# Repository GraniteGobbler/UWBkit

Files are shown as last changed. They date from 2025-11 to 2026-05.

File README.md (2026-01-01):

# UWBkit

This is a repository containing firmware from two other repositories and is released under their license:
- [DWM3001C-starter-firmware](https://github.com/Uberi/DWM3001C-starter-firmware), by Uberi (as of [02c341b](https://github.com/Uberi/DWM3001C-starter-firmware/commit/02c341b4f58dd8410239b5278b40aece675a3650))
- [SSD1306-LCD-on-NRF52](https://github.com/jimmywong2003/SSD1306-LCD-on-NRF52), by jimmywong2003 (as of [4ca746a](https://github.com/jimmywong2003/SSD1306-LCD-on-NRF52/commit/4ca746a075d3628c971d63ee42bb9b67d5787345))

All other files are released under the [Creative Commons CC0 license](https://creativecommons.org/public-domain/cc0/).

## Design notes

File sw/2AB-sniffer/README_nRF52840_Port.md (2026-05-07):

# DWM3001C Starter Firmware – nRF52840 Port

This directory contains all files needed to build the
[DWM3001C starter firmware](https://github.com/Uberi/DWM3001C-starter-firmware)
for an **nRF52840**-based board inside **SEGGER Embedded Studio (SES) v7+**.

---

## Files in this port

| File | Purpose |
|---|---|
| `dw3000_api_nrf52840.emProject` | SES solution/project file (drop-in replacement for the original `dw3000_api.emProject`) |
| `flash_placement_nrf52840.xml` | Linker section-placement descriptor (1 MB Flash, 256 KB RAM) |
| `Setup/SEGGER_Flash_nrf52840.icf` | IAR/SEGGER linker script for nRF52840 |
| `Src/platform/custom_board_nrf52840.h` | GPIO / SPI pin definitions for the DW3000 ↔ nRF52840 wiring |
| `Src/platform/sdk_config_nrf52840.h` | nRF5 SDK `sdk_config` overrides (SPIM3, GPIOTE, logging, …) |

---

## Key differences from the nRF52833 (DWM3001C) project

| Setting | nRF52833 (original) | nRF52840 (this port) |
|---|---|---|
| `arm_target_device_name` | `nRF52833_xxAA` | `nRF52840_xxAA` |
| Preprocessor define | `NRF52833_XXAA` | `NRF52840_XXAA` |
| System init | `system_nrf52833.c` | `system_nrf52840.c` |
| Startup files | `ses_startup_nrf52833.s` | `ses_startup_nrf52840.s` |
| SVD file | `nrf52833.svd` | `nrf52840.svd` |
| Flash size | 512 KB (0x80000) | 1 MB (0x100000) |
| RAM size | 128 KB (0x20000) | **256 KB (0x40000)** |
| Linker script | `Setup/SEGGER_Flash.icf` | `Setup/SEGGER_Flash_nrf52840.icf` |
| Flash placement XML | `flash_placement.xml` | `flash_placement_nrf52840.xml` |

The SPI peripheral (SPIM3, 32 MHz capable) and the nrfx/legacy driver layer are
identical between the two chips, so **no changes to `deca_spi.c`, `port.c`, or any
example source files are required.**

---

## Prerequisites

1. **SEGGER Embedded Studio** v7.x (free for Nordic targets).
2. **nRF5 SDK 17.1.0** (`nRF5_SDK_17.1.0_ddde560`) extracted to
   `/usr/local/nRF5_SDK_17.1.0_ddde560` **or** update the `NordicSDKDir` macro
   inside `dw3000_api_nrf52840.emProject` to match your installation path.
3. A **J-Link** (on-board on nRF52840-DK) for flashing and RTT logging.

---

## Setup steps

### 1 – Copy port files into the repository

Copy all files from this port directory into the root of the cloned
`DWM3001C-starter-firmware` repository, preserving the directory structure:

```
DWM3001C-starter-firmware/
├── dw3000_api_nrf52840.emProject      ← new
├── flash_placement_nrf52840.xml       ← new
├── Setup/
│   ├── SEGGER_Flash.icf               (original, untouched)
│   └── SEGGER_Flash_nrf52840.icf      ← new
└── Src/
    └── platform/
        ├── custom_board_nrf52840.h    ← new
        ├── sdk_config_nrf52840.h      ← new
        └── ... (original files unchanged)
```

### 2 – Tell the SDK about the custom board

The project uses `BOARD_CUSTOM`.  The nRF5 SDK expects a file called `custom_board.h`
on the include path.  Create a thin wrapper in `Src/platform/custom_board.h`:

```c
/* Src/platform/custom_board.h */
#pragma once
#include "custom_board_nrf52840.h"
```

> If you already have a `custom_board.h` for a different board, rename it and
> adjust the include accordingly.

### 3 – Set the NordicSDKDir macro

In SES: **Tools → Options → Building → Global macros**, set:

```
NordicSDKDir=<absolute path to nRF5_SDK_17.1.0_ddde560>
```

Or edit the `macros` attribute directly in `dw3000_api_nrf52840.emProject`.

### 4 – Open and build

1. Open `dw3000_api_nrf52840.emProject` in SES.
2. Select the **Debug** configuration.
3. Choose the example to run by editing `Src/main.c` (same as the original project).
4. Build (**F7**) and flash (**F5**).

---

## Pin wiring (nRF52840-DK default)

| DW3000 signal | nRF52840 GPIO | nRF52840-DK header |
|---|---|---|
| SPI CLK | P0.03 | D13 |
| SPI MOSI | P0.04 | D11 |
| SPI MISO | P0.28 | D12 |
| SPI CS | P0.29 | D10 |
| IRQ | P0.30 | D9 |
| RST | P0.31 | D8 |
| WAKEUP | P0.02 | D7 |

Adjust `custom_board_nrf52840.h` if your hardware uses different pins.

---

## Troubleshooting

| Symptom | Likely cause | Fix |
|---|---|-----|
| Build error: `nrf52840.h not found` | Wrong SDK path | Update `NordicSDKDir` |
| Build error: `ses_startup_nrf52840.s not found` | SDK < 15.3 | Use SDK 17.1.0 |
| Device not recognised by J-Link | Wrong target in project | Confirm `arm_target_device_name="nRF52840_xxAA"` |
| SPI transfer returns garbage | Wrong pin numbers | Re-check `custom_board_nrf52840.h` |
| RTT output missing | `NRF_LOG_BACKEND_RTT_ENABLED` not set | Ensure `sdk_config_nrf52840.h` is included |

---

## License

This port is provided under the same terms as the upstream project (Apache 2.0).
The nRF5 SDK files referenced by the project file are subject to Nordic's
[5-clause Nordic license](https://developer.nordicsemi.com/nRF5_SDK/nRF5_SDK_v17.x.x/sdk_license.zip).

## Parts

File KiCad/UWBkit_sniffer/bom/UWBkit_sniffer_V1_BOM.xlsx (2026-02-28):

Reference | Qty | Qty Owned | Qty Need | Value | Footprint | Mouser link
ANT1 | 1 | 0 | 1 | Taoglas_UWC.20 | UWB_Antennas:Taoglas_UWC.20 | https://cz.mouser.com/ProductDetail/Taoglas/UWC.20?qs=MLItCLRbWswWjiq9Fti3WQ%3D%3D
C1,C3,C6,C9,C11,C12 | 6 | 6 | 0 | 100n | Capacitor_SMD:C_0603_1608Metric
C2,C4 | 2 | 8 | -6 | 10u | Capacitor_Tantalum_SMD:CP_EIA-3216-18_Kemet-A
C5 | 1 | 0 | 1 | 0R | Capacitor_SMD:C_0603_1608Metric | https://cz.mouser.com/ProductDetail/Panasonic/ERJ-H3G0R00V?qs=eP2BKZSCXI4lQ49QwEWHxw%3D%3D
C7,C8 | 2 | 6 | -4 | 10u | Capacitor_SMD:C_0603_1608Metric
C10 | 1 | 0 | 1 | 1u | Capacitor_Tantalum_SMD:CP_EIA-3216-18_Kemet-A | https://cz.mouser.com/ProductDetail/KEMET/T491A105K020ATAUTO?qs=WOKUqv%2F%2FT%2Fa0doDrQU37QA%3D%3D
D1,D2,D4,D5 | 4 | 4 | 0 | R | LED_SMD:LED_0603_1608Metric
D3,D6 | 2 | 2 | 0 | G | LED_SMD:LED_0603_1608Metric
H1,H2,H3,H4 | 4 | 4 | 0 | MountingHole_Pad | MountingHole:MountingHole_3.2mm_M3_Pad_Via
J1 | 1 | 1 | 0 | Conn_I2C1 | Connector_PinSocket_2.54mm:PinSocket_1x04_P2.54mm_Vertical
J2 | 1 | 1 | 0 | Conn_I2C2 | Connector_PinSocket_2.54mm:PinSocket_1x04_P2.54mm_Vertical
J3 | 1 | 1 | 0 | Conn_01x03 | Connector_PinSocket_2.54mm:PinSocket_1x03_P2.54mm_Vertical
J4 | 1 | 1 | 0 | Conn_SPIS | Connector_PinSocket_2.54mm:PinSocket_1x07_P2.54mm_Vertical
J5 | 1 | 1 | 0 | Conn_SPIM | Connector_PinSocket_2.54mm:PinSocket_1x07_P2.54mm_Vertical
J6 | 1 | 0 | 1 | Conn_SWD | Connector_PinHeader_1.27mm:PinHeader_2x05_P1.27mm_Vertical_SMD | https://cz.mouser.com/ProductDetail/Samtec/FTSH-105-01-F-DV-K-A?qs=rU5fayqh%252BE2B26KBQKnaPw%3D%3D
J7 | 1 | 1 | 0 | Conn_GPIO | Connector_PinSocket_2.54mm:PinSocket_2x04_P2.54mm_Vertical
J8 | 1 | 0 | 1 | Conn_Coaxial | Connector_Coaxial:SMA_Molex_73251-1153_EdgeMount_Horizontal | https://cz.mouser.com/ProductDetail/Molex/73251-1153?qs=vxeUf0TWHS0zlj4xWb5GCw%3D%3D
J9 | 1 | 1 | 0 | Conn_01x02 | Connector_PinHeader_2.54mm:PinHeader_1x02_P2.54mm_Vertical
J10,J11 | 2 | 1 | 1 | USB_C_Receptacle_USB2.0_14P | Connector_USB:USB_C_Receptacle_GCT_USB4105-xx-A_16P_TopMnt_Horizontal | https://cz.mouser.com/ProductDetail/GCT/USB4105-GF-A?qs=KUoIvG%2F9IlY%2FMLlBMpStpA%3D%3D
L1,L2 (DNP) | 2 | 2 | 0 | L | Inductor_SMD:L_0603_1608Metric
L3 | 1 | 8 | -7 | 2.2u | Inductor_SMD:L_0805_2012Metric
R1,R2,R9 (DNP) | 3 | 3 | 0 | 0R | Resistor_SMD:R_0603_1608Metric
R3,R11 | 2 | 15 | -13 | 100k | Resistor_SMD:R_0603_1608Metric
R4,R5,R10,R15 | 4 | 0 | 4 | 3k3 | Resistor_SMD:R_0603_1608Metric | https://cz.mouser.com/ProductDetail/YAGEO/RC0603FR-073K3L?qs=gt6vzsuosg2EoNiKbtAsfQ%3D%3D
R6,R16 | 2 | 0 | 2 | 2k1 | Resistor_SMD:R_0603_1608Metric | https://cz.mouser.com/ProductDetail/YAGEO/RC0603FR-072K1L?qs=IuGqVx9wL0IQ8qvrNmtVmg%3D%3D
R7,R8,R13 | 3 | 3 | 0 | 0R | Resistor_SMD:R_0603_1608Metric
R12 | 1 | 0 | 1 | 24k | Resistor_SMD:R_0603_1608Metric | https://cz.mouser.com/ProductDetail/YAGEO/RC0603FR-1024KL?qs=EiqXWrxQq63LblM5DPLYDA%3D%3D
R14 | 1 | 0 | 1 | 47k | Resistor_SMD:R_0603_1608Metric | https://cz.mouser.com/ProductDetail/YAGEO/AC0603FR-1347KL?qs=1mbolxNpo8d0iSUsjFUAXQ%3D%3D
R17,R18,R20,R21 | 4 | 6 | -2 | 5k1 | Resistor_SMD:R_0603_1608Metric
R19,R22 | 2 | 8 | -6 | 10k | Resistor_SMD:R_0603_1608Metric
SW1 | 1 | 1 | 0 | SW_Push | Button_Switch_THT:SW_TH_Tactile_Omron_B3F-106x
U1 | 1 | 0 | 1 | LBUA5QJ2AB | LBUA5QJ2AB:LBUA5QJ2AB | https://cz.mouser.com/ProductDetail/Murata/LBUA5QJ2AB-828?qs=By6Nw2ByBD3tGvEImOEzYQ%3D%3D
U2 | 1 | 0 | 1 | XC9285B33CMR-G | Package_TO_SOT_SMD:SOT-23-5 | https://cz.mouser.com/ProductDetail/Torex-Semiconductor/XC9285B33CMR-G?qs=dbcCsuKDzFUopNkosMcCjA%3D%3D
U3 | 1 | 0 | 1 | CP2104 | Package_DFN_QFN:QFN-24-1EP_4x4mm_P0.5mm_EP2.6x2.6mm | https://cz.mouser.com/ProductDetail/Silicon-Labs/CP2104-F03-GMR?qs=1CB38rTTsYrRJKVkczeRzA%3D%3D
U4,U5 | 2 | 1 | 1 | IP4234CZ6 | Package_TO_SOT_SMD:SC-74-6_1.55x2.9mm_P0.95mm | https://cz.mouser.com/ProductDetail/STMicroelectronics/USBLC6-4SC6Y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
0R |  |  | 7

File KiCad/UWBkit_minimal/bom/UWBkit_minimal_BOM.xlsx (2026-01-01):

Reference | Qty | Value | Footprint |  | Mouser link
BT1 | 1 | CR2032 | Battery:BatteryHolder_Keystone_1058_1x2032 | https://cz.mouser.com/ProductDetail/Keystone-Electronics/1058?qs=1Og3oR3ILyCdlFdchHwycQ%3D%3D | https://cz.mouser.com/ProductDetail/Keystone-Electronics/1058?qs=1Og3oR3ILyCdlFdchHwycQ%3D%3D
C1,C3,C4 | 3 | 100n | Capacitor_SMD:C_0603_1608Metric | https://cz.mouser.com/ProductDetail/YAGEO/CC0603JRX7R9BB104?qs=57cj7OiSijmjSM%252BQadQODQ%3D%3D | https://cz.mouser.com/ProductDetail/YAGEO/CC0603JRX7R9BB104?qs=57cj7OiSijmjSM%252BQadQODQ%3D%3D
C2 | 1 | 10u | Capacitor_Tantalum_SMD:CP_EIA-3216-18_Kemet-A | https://cz.mouser.com/ProductDetail/KEMET/T491A106K010AT7280?qs=sGAEpiMZZMtZ1n0r9vR22Xj1zlb9nzH05nChlkMPHIM%3D | https://cz.mouser.com/ProductDetail/KEMET/T491A106K010AT7280?qs=sGAEpiMZZMtZ1n0r9vR22Xj1zlb9nzH05nChlkMPHIM%3D
C5,C6 | 2 | 10u | Capacitor_SMD:C_0603_1608Metric | https://cz.mouser.com/ProductDetail/Murata-Electronics/GRM188Z71A106KA73D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 | https://cz.mouser.com/ProductDetail/Murata-Electronics/GRM188Z71A106KA73D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
D1 | 1 | G | LED_SMD:LED_0603_1608Metric | https://cz.mouser.com/ProductDetail/Wurth-Elektronik/150060GS83000?qs=3GbUB62Nf7fgC6%2FTmce6tQ%3D%3D | https://cz.mouser.com/ProductDetail/Wurth-Elektronik/150060GS83000?qs=3GbUB62Nf7fgC6%2FTmce6tQ%3D%3D
D2 | 1 | B | LED_SMD:LED_0603_1608Metric | https://cz.mouser.com/ProductDetail/Wurth-Elektronik/150060BS83000?qs=3GbUB62Nf7dydBCOIPGfOA%3D%3D | https://cz.mouser.com/ProductDetail/Wurth-Elektronik/150060BS83000?qs=3GbUB62Nf7dydBCOIPGfOA%3D%3D
D3,D5,D6 | 3 | R | LED_SMD:LED_0603_1608Metric | https://cz.mouser.com/ProductDetail/Wurth-Elektronik/150060RS83000?qs=3GbUB62Nf7cMzk8OPkCLhg%3D%3D | https://cz.mouser.com/ProductDetail/Wurth-Elektronik/150060RS83000?qs=3GbUB62Nf7cMzk8OPkCLhg%3D%3D
D4 | 1 | LSG T676-P7R-1-0+N7P9-24 | LED_Dual:LED_Dual_OSRAM-PLCC4_3.2x2.8mm | https://cz.mouser.com/ProductDetail/ams-OSRAM/LSG-T676-P7R-1-0%2bN7P9-24?qs=74fRo9GAWsxURNkIJamEtQ%3D%3D | https://cz.mouser.com/ProductDetail/ams-OSRAM/LSG-T676-P7R-1-0%2bN7P9-24?qs=74fRo9GAWsxURNkIJamEtQ%3D%3D
D7 | 1 | PESD5V2S2UT | Package_TO_SOT_SMD:SOT-23 | https://cz.mouser.com/ProductDetail/Nexperia/PESD5V2S2UT-QR?qs=vvQtp7zwQdMj81rXubab%2Fw%3D%3D | https://cz.mouser.com/ProductDetail/Nexperia/PESD5V2S2UT-QR?qs=vvQtp7zwQdMj81rXubab%2Fw%3D%3D
J1 | 1 | Conn_UART | Connector_PinSocket_2.54mm:PinSocket_1x04_P2.54mm_Vertical | https://cz.mouser.com/ProductDetail/Samtec/SSQ-104-01-G-S?qs=rU5fayqh%252BE3vCiJshtNkaw%3D%3D | https://cz.mouser.com/ProductDetail/Samtec/SSQ-104-01-G-S?qs=rU5fayqh%252BE3vCiJshtNkaw%3D%3D
J2 | 1 | Conn_SWD | Connector_PinHeader_1.27mm:PinHeader_2x05_P1.27mm_Vertical_SMD | https://cz.mouser.com/ProductDetail/Samtec/SHF-105-01-L-D-SM?qs=92ilVni64gzDB%252BvALG5zyg%3D%3D | https://cz.mouser.com/ProductDetail/Samtec/SHF-105-01-L-D-SM?qs=92ilVni64gzDB%252BvALG5zyg%3D%3D
J3 | 1 | USB_C_Receptacle_USB2.0_14P | Connector_USB:USB_C_Receptacle_GCT_USB4105-xx-A_16P_TopMnt_Horizontal | https://cz.mouser.com/ProductDetail/GCT/USB4105-GF-A?qs=KUoIvG%2F9IlY%2FMLlBMpStpA%3D%3D | https://cz.mouser.com/ProductDetail/GCT/USB4105-GF-A?qs=KUoIvG%2F9IlY%2FMLlBMpStpA%3D%3D
J4 | 1 | Conn_BATT | Connector_PinSocket_2.54mm:PinSocket_1x02_P2.54mm_Vertical | https://cz.mouser.com/ProductDetail/Amphenol-FCI/76308-102LF?qs=5xI8GKdkXlk3acvGut782g%3D%3D | https://cz.mouser.com/ProductDetail/Amphenol-FCI/76308-102LF?qs=5xI8GKdkXlk3acvGut782g%3D%3D
J5 | 1 | Jumper_Cell_NO | Connector_PinHeader_2.54mm:PinHeader_1x02_P2.54mm_Vertical | https://cz.mouser.com/ProductDetail/Amphenol-FCI/10129378-910002BLF?qs=0lQeLiL1qyYh8zFHsKDebQ%3D%3D | https://cz.mouser.com/ProductDetail/Amphenol-FCI/10129378-910002BLF?qs=0lQeLiL1qyYh8zFHsKDebQ%3D%3D
L1 | 1 | 2.2u | Inductor_SMD:L_0805_2012Metric | https://cz.mouser.com/ProductDetail/TDK/MLZ2012M2R2HT000?qs=%2FPzWLGNeQ%252BjH4aKH16QzxA%3D%3D | https://cz.mouser.com/ProductDetail/TDK/MLZ2012M2R2HT000?qs=%2FPzWLGNeQ%252BjH4aKH16QzxA%3D%3D
Q1,Q2 | 2 | BSS138 | Package_TO_SOT_SMD:SOT-23 | https://cz.mouser.com/ProductDetail/onsemi-Fairchild/BSS138?qs=HK%252BeIG1iaahCeqBvjB4arg%3D%3D | https://cz.mouser.com/ProductDetail/onsemi-Fairchild/BSS138?qs=HK%252BeIG1iaahCeqBvjB4arg%3D%3D
Q3 | 1 | BSS84 | Package_TO_SOT_SMD:SOT-23-3 | https://cz.mouser.com/ProductDetail/onsemi-Fairchild/BSS84?qs=FOlmdCx%252BAA0e83h5MpSc0g%3D%3D | https://cz.mouser.com/ProductDetail/onsemi-Fairchild/BSS84?qs=FOlmdCx%252BAA0e83h5MpSc0g%3D%3D
R1 | 1 | 200R | Resistor_SMD:R_0603_1608Metric | https://cz.mouser.com/ProductDetail/YAGEO/RT0603DRD07200RL | https://cz.mouser.com/ProductDetail/YAGEO/RT0603DRD07200RL
R2 | 1 | 30R | Resistor_SMD:R_0603_1608Metric | https://cz.mouser.com/ProductDetail/YAGEO/RT0603DRE0730RL?qs=sGAEpiMZZMvdGkrng054t98Xz4DA4UW4YZV2RawqRNs%3D | https://cz.mouser.com/ProductDetail/YAGEO/RT0603DRE0730RL?qs=sGAEpiMZZMvdGkrng054t98Xz4DA4UW4YZV2RawqRNs%3D
R3 | 1 | 150R | Resistor_SMD:R_0603_1608Metric | https://cz.mouser.com/ProductDetail/YAGEO/AC0603FR-10150RL | https://cz.mouser.com/ProductDetail/YAGEO/AC0603FR-10150RL
R4 | 1 | 330R | Resistor_SMD:R_0603_1608Metric | https://cz.mouser.com/ProductDetail/YAGEO/RE0603FRE07330RL | https://cz.mouser.com/ProductDetail/YAGEO/RE0603FRE07330RL
R5 | 1 | 220R | Resistor_SMD:R_0603_1608Metric | https://cz.mouser.com/ProductDetail/Vishay/CRCW0603220RFKEC | https://cz.mouser.com/ProductDetail/Vishay/CRCW0603220RFKEC
R6,R9,R15 | 3 | 300R | Resistor_SMD:R_0603_1608Metric | https://cz.mouser.com/ProductDetail/Panasonic/ERA-3AEB301V | https://cz.mouser.com/ProductDetail/Panasonic/ERA-3AEB301V
R7,R8 | 2 | 5k1 | Resistor_SMD:R_0603_1608Metric | https://cz.mouser.com/ProductDetail/Vishay/CRCW06035K10FKEBC | https://cz.mouser.com/ProductDetail/Vishay/CRCW06035K10FKEBC
R10,R11 | 2 | 1k | Resistor_SMD:R_0603_1608Metric | https://cz.mouser.com/ProductDetail/Vishay-Draloric/RCA06031K00FKEA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 | https://cz.mouser.com/ProductDetail/Vishay-Draloric/RCA06031K00FKEA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
R12,R13,R16 | 3 | 100k | Resistor_SMD:R_0603_1608Metric | https://cz.mouser.com/ProductDetail/YAGEO/RT0603BRD07100KL | https://cz.mouser.com/ProductDetail/YAGEO/RT0603BRD07100KL
R14 | 1 | 10k | Resistor_SMD:R_0603_1608Metric | https://cz.mouser.com/ProductDetail/YAGEO/RC0603FR-7W10KL | https://cz.mouser.com/ProductDetail/YAGEO/RC0603FR-7W10KL
SW1 | 1 | SW_Push | Button_Switch_THT:SW_TH_Tactile_Omron_B3F-106x | https://cz.mouser.com/ProductDetail/Omron-Electronics/B3F-1060 | https://cz.mouser.com/ProductDetail/Omron-Electronics/B3F-1060
U2 | 1 | IP4234CZ6 | Package_TO_SOT_SMD:SC-74-6_1.55x2.9mm_P0.95mm | https://cz.mouser.com/ProductDetail/Nexperia/IP4234CZ6125?qs=sSXnapcmqSskfgXn%2F9aKzA%3D%3D | https://cz.mouser.com/ProductDetail/Nexperia/IP4234CZ6125?qs=sSXnapcmqSskfgXn%2F9aKzA%3D%3D
U3 | 1 | MAX40203AUK+T | Package_TO_SOT_SMD:SOT-23-5 | https://cz.mouser.com/ProductDetail/Analog-Devices-Maxim-Integrated/MAX40203AUK%2bT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 | https://cz.mouser.com/ProductDetail/Analog-Devices-Maxim-Integrated/MAX40203AUK%2bT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
U4 | 1 | XC9285B33CMR-G | Package_TO_SOT_SMD:SOT-23-5 | https://cz.mouser.com/ProductDetail/Torex-Semiconductor/XC9285B33CMR-G?qs=dbcCsuKDzFUopNkosMcCjA%3D%3D | https://cz.mouser.com/ProductDetail/Torex-Semiconductor/XC9285B33CMR-G?qs=dbcCsuKDzFUopNkosMcCjA%3D%3D

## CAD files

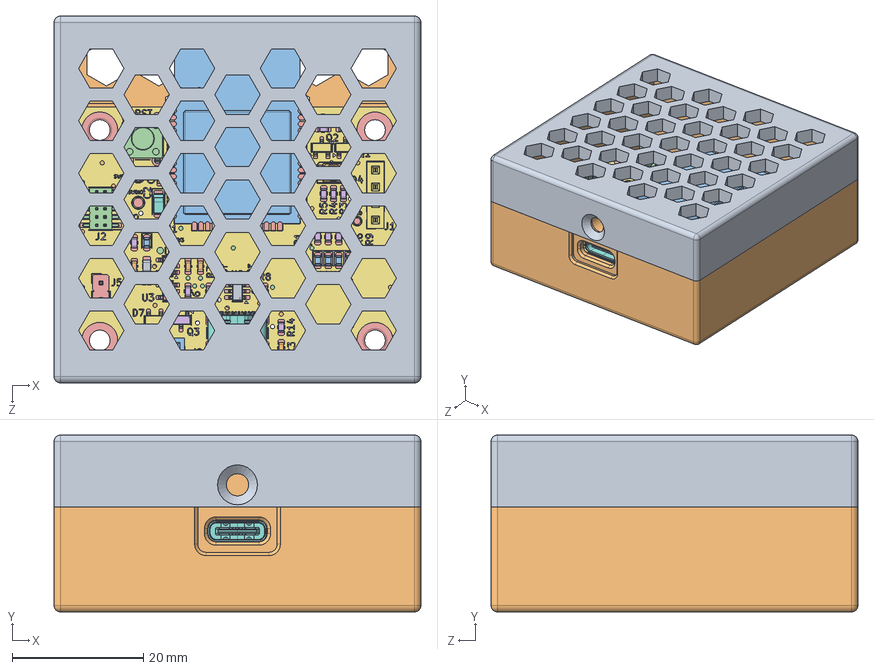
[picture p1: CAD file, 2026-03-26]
hw/UWBkit_minimal/Assem1.SLDASM
56.0 x 27.0 x 56.0 mm
case
lid
LED_0603_1608Metric.step x 5
SW_PUSH_6mm_H7.3mm.step
SOT-23-5.step x 2
R_0603_1608Metric.step x 16
SOT-23.step x 3
CP_EIA-3216-18_Kemet-A.step
L_0805_2012Metric.step
C_0603_1608Metric.step x 5
PinSocket_1x02_P2.54mm_Vertical.step
PinHeader_2x05_P1.27mm_Vertical_SMD.step
PinHeader_1x02_P2.54mm_Vertical.step
SOT-23-3.step
PinSocket_1x04_P2.54mm_Vertical.step
USB_C_Receptacle_GCT_USB4105-xx-A_16P_TopMnt_Horizontal.step
SC-74-6_1.55x2.9mm_P0.95mm.step
LED_RGB_Wuerth-PLCC4_3.2x2.8mm_150141M173100.step
DWM3001C.step
BatteryHolder_Keystone_1058_1x2032.step
UWBkit_minimal_pad.step
UWBkit_minimal_silkscreen.step
UWBkit_minimal_soldermask.step

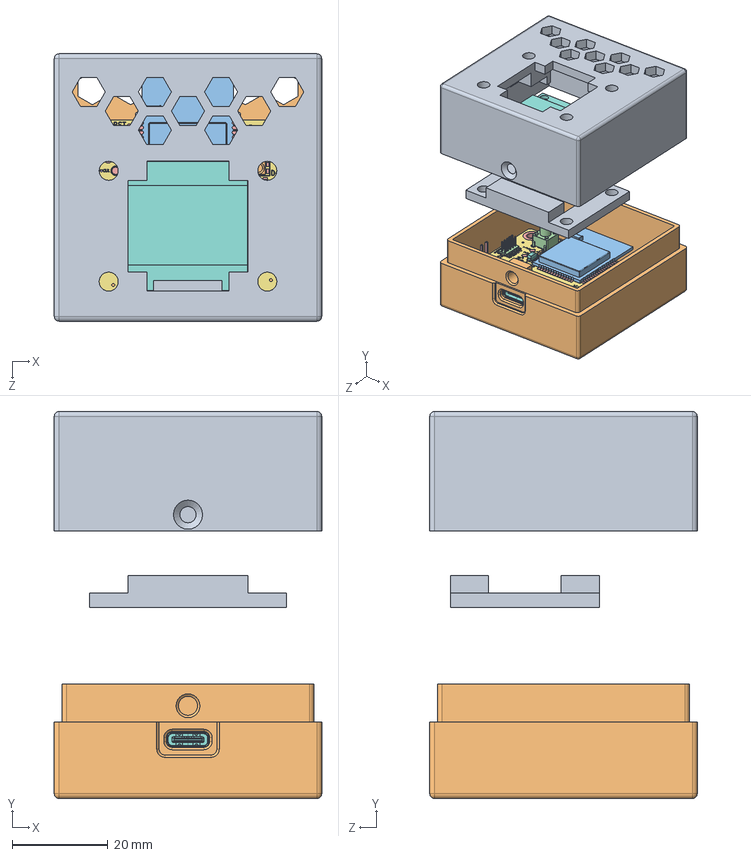
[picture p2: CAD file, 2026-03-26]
hw/UWBkit_minimal/Assem_oled.SLDASM
56.0 x 81.0 x 56.0 mm
case
LED_0603_1608Metric.step x 5
SW_PUSH_6mm_H7.3mm.step
SOT-23-5.step x 2
R_0603_1608Metric.step x 16
SOT-23.step x 3
CP_EIA-3216-18_Kemet-A.step
L_0805_2012Metric.step
C_0603_1608Metric.step x 5
PinSocket_1x02_P2.54mm_Vertical.step
PinHeader_2x05_P1.27mm_Vertical_SMD.step
PinHeader_1x02_P2.54mm_Vertical.step
SOT-23-3.step
PinSocket_1x04_P2.54mm_Vertical.step
USB_C_Receptacle_GCT_USB4105-xx-A_16P_TopMnt_Horizontal.step
SC-74-6_1.55x2.9mm_P0.95mm.step
LED_RGB_Wuerth-PLCC4_3.2x2.8mm_150141M173100.step
DWM3001C.step
BatteryHolder_Keystone_1058_1x2032.step
UWBkit_minimal_pad.step
UWBkit_minimal_silkscreen.step
UWBkit_minimal_soldermask.step
oled
oled_holder
lid_oled

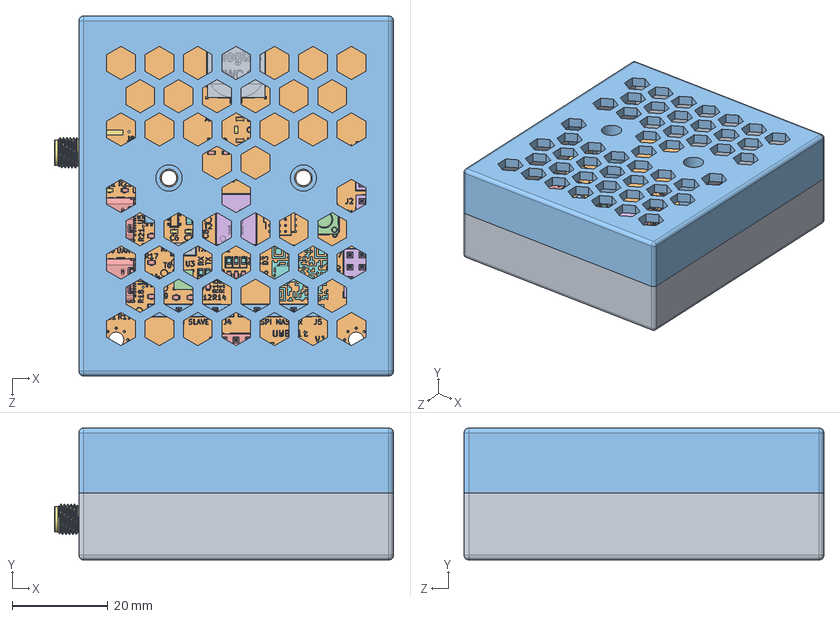
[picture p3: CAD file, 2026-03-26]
hw/UWBkit_sniffer/Assembly.SLDASM
70.6 x 27.5 x 75.0 mm
case_bottom
FTSH-105-01-F-DV-K-A_body.step
FTSH-105-01-F-DV-K_pins1.step
FTSH-105-01-F-DV-K_pins2.step
R_0603_1608Metric.step x 22
PinSocket_1x04_P2.54mm_Vertical.step x 2
C_0603_1608Metric.step x 9
LED_0603_1608Metric.step x 6
PinHeader_1x02_P2.54mm_Vertical.step
L_0603_1608Metric.step x 2
SC-74-6_1.55x2.9mm_P0.95mm.step x 2
QFN-24-1EP_4x4mm_P0.5mm_EP2.6x2.6mm.step
USB_C_Receptacle_GCT_USB4105-xx-A_16P_TopMnt_Horizontal.step x 2
PinSocket_2x04_P2.54mm_Vertical.step
SMA_Molex_73251-1153_EdgeMount_Horizontal.step
L_0805_2012Metric.step
UWC.20.step
SOT-23-5.step
PinSocket_1x07_P2.54mm_Vertical.step x 2
SW_TH_Tactile_Omron_B3F-106x.step
PinSocket_1x03_P2.54mm_Vertical.step
Type2AB.step
CP_EIA-3216-18_Kemet-A.step x 3
UWBkit_sniffer_silkscreen.step
UWBkit_sniffer_silkscreen-0.step
UWBkit_sniffer_PCB.step
case_lid

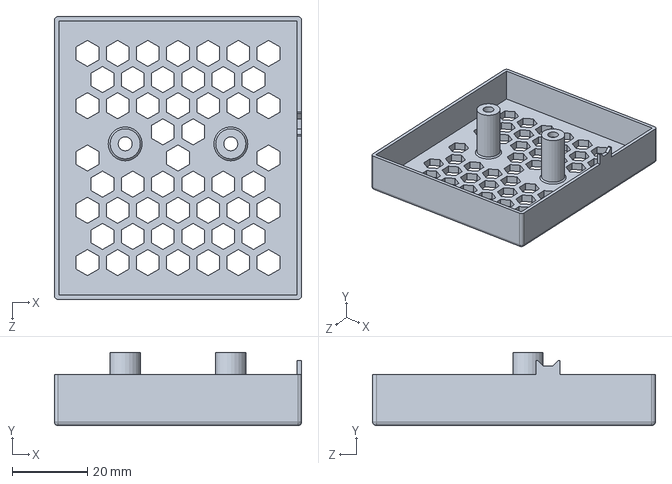
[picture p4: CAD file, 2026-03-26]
hw/UWBkit_sniffer/case_lid.SLDPRT
65.6 x 19.4 x 75.0 mm

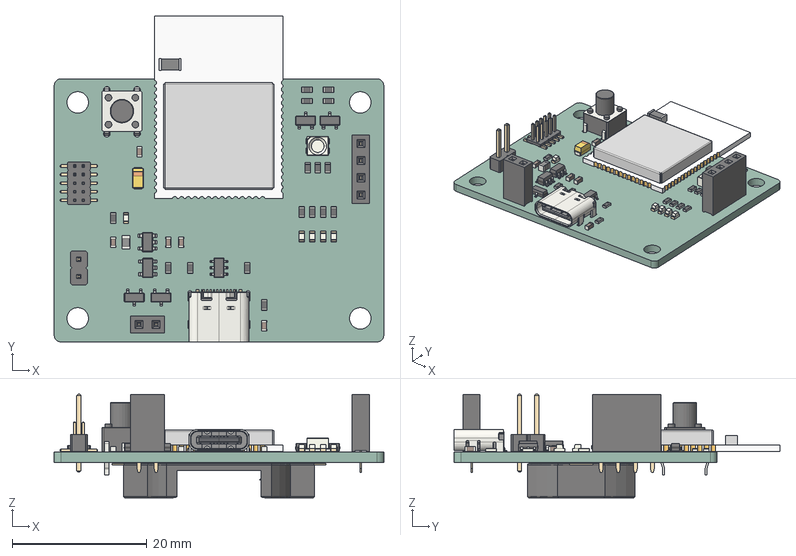
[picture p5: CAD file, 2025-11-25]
KiCad/UWBkit_minimal/UWBkit_minimal.step
49.0 x 48.5 x 15.4 mm
LED_0603_1608Metric x 5
SW_PUSH_6mm_H7.3mm
SOT-23-5 x 2
R_0603_1608Metric x 16
SOT-23 x 3
CP_EIA-3216-18_Kemet-A
L_0805_2012Metric
C_0603_1608Metric x 5
PinSocket_1x02_P2.54mm_Vertical
PinHeader_2x05_P1.27mm_Vertical_SMD
PinHeader_1x02_P2.54mm_Vertical
SOT-23-3
PinSocket_1x04_P2.54mm_Vertical
USB_C_Receptacle_GCT_USB4105-xx-A_16P_TopMnt_Horizontal
SC-74-6_1.55x2.9mm_P0.95mm
LED_RGB_Wuerth-PLCC4_3.2x2.8mm_150141M173100
DWM3001C
BatteryHolder_Keystone_1058_1x2032
UWBkit_minimal_PCB

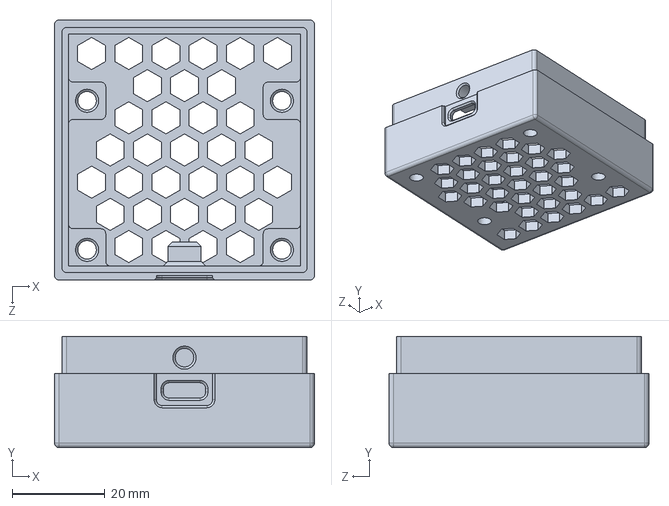
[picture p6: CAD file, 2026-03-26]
hw/UWBkit_minimal/case.SLDPRT
56.0 x 24.0 x 56.0 mm

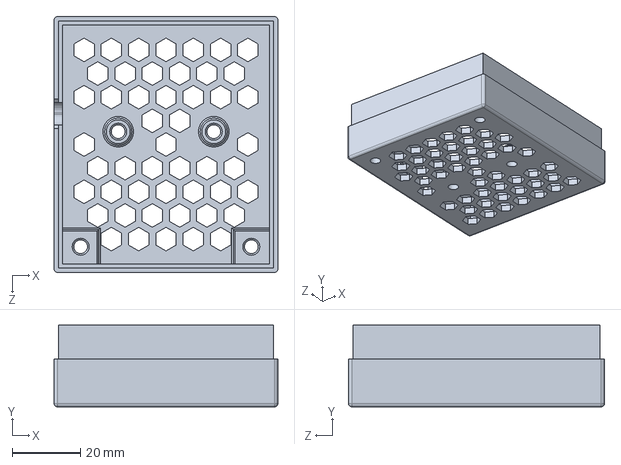
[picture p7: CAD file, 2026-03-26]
hw/UWBkit_sniffer/case_bottom.SLDPRT
65.6 x 24.0 x 75.0 mm

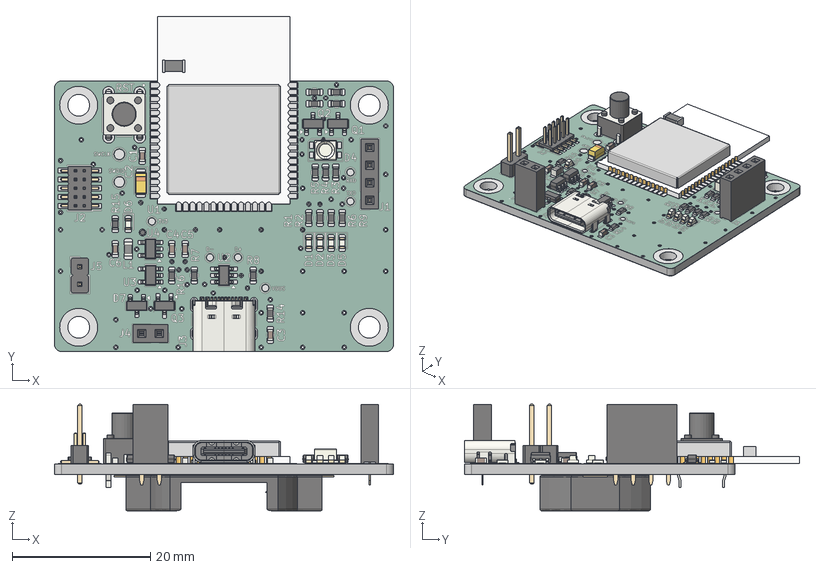
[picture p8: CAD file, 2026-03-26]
hw/UWBkit_minimal/UWBkit_minimal.step
49.0 x 48.5 x 15.4 mm
LED_0603_1608Metric x 5
SW_PUSH_6mm_H7.3mm
SOT-23-5 x 2
R_0603_1608Metric x 16
SOT-23 x 3
CP_EIA-3216-18_Kemet-A
L_0805_2012Metric
C_0603_1608Metric x 5
PinSocket_1x02_P2.54mm_Vertical
PinHeader_2x05_P1.27mm_Vertical_SMD
PinHeader_1x02_P2.54mm_Vertical
SOT-23-3
PinSocket_1x04_P2.54mm_Vertical
USB_C_Receptacle_GCT_USB4105-xx-A_16P_TopMnt_Horizontal
SC-74-6_1.55x2.9mm_P0.95mm
LED_RGB_Wuerth-PLCC4_3.2x2.8mm_150141M173100
DWM3001C
BatteryHolder_Keystone_1058_1x2032
UWBkit_minimal_pad
UWBkit_minimal_silkscreen
UWBkit_minimal_soldermask
UWBkit_minimal_PCB

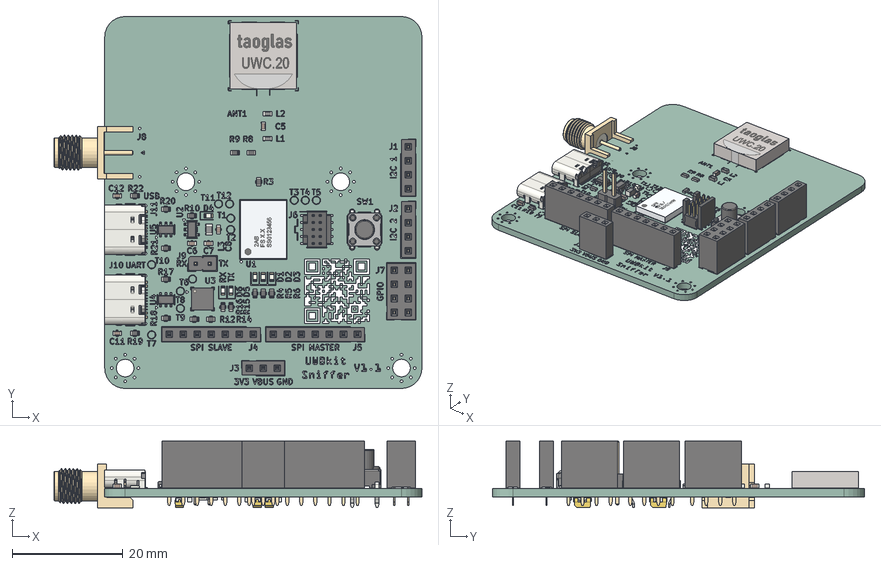
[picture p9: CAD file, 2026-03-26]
hw/UWBkit_sniffer/UWBkit_sniffer.step
66.6 x 67.3 x 12.1 mm
R_0603_1608Metric x 22
PinSocket_1x04_P2.54mm_Vertical x 2
C_0603_1608Metric x 9
FTSH-105-01-F-DV-K-A_body
FTSH-105-01-F-DV-K_pins1
FTSH-105-01-F-DV-K_pins2
LED_0603_1608Metric x 6
PinHeader_1x02_P2.54mm_Vertical
L_0603_1608Metric x 2
SC-74-6_1.55x2.9mm_P0.95mm x 2
QFN-24-1EP_4x4mm_P0.5mm_EP2.6x2.6mm
USB_C_Receptacle_GCT_USB4105-xx-A_16P_TopMnt_Horizontal x 2
PinSocket_2x04_P2.54mm_Vertical
SMA_Molex_73251-1153_EdgeMount_Horizontal
L_0805_2012Metric
UWC.20
SOT-23-5
PinSocket_1x07_P2.54mm_Vertical x 2
SW_TH_Tactile_Omron_B3F-106x
PinSocket_1x03_P2.54mm_Vertical
Type2AB
CP_EIA-3216-18_Kemet-A x 3
UWBkit_sniffer_silkscreen x 2
UWBkit_sniffer_PCB

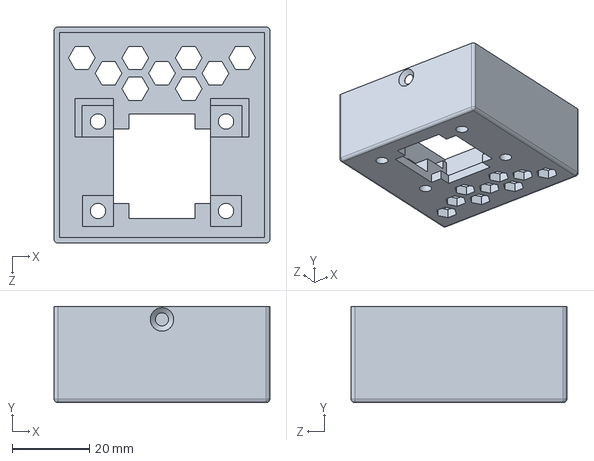
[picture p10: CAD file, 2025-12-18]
hw/UWBkit_minimal/lid_oled.SLDPRT
56.0 x 25.0 x 56.0 mm

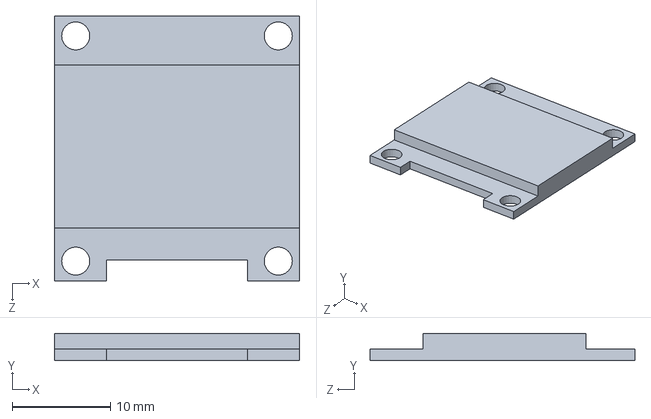
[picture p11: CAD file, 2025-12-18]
hw/UWBkit_minimal/oled.SLDPRT
25.0 x 2.80 x 27.0 mm

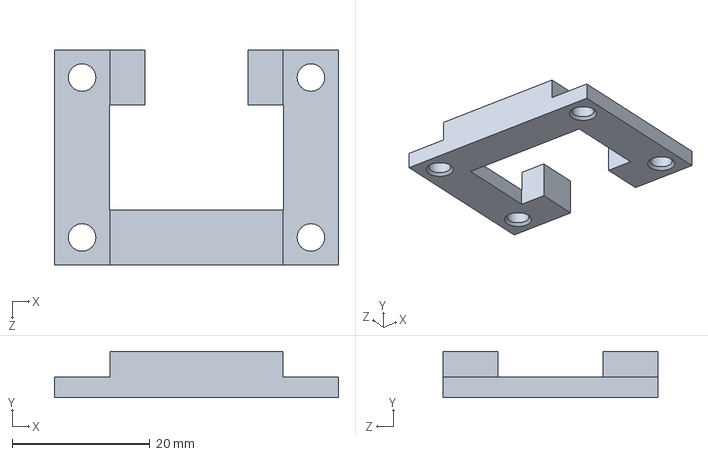
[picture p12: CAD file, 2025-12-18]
hw/UWBkit_minimal/oled_holder.SLDPRT
41.2 x 6.70 x 31.2 mm

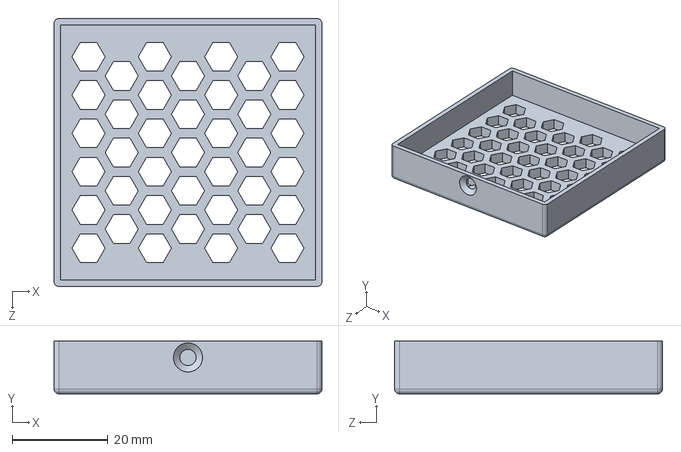
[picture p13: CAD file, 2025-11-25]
hw/UWBkit_minimal/lid.SLDPRT
56.0 x 11.0 x 56.0 mm

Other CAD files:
hw/UWBkit_sniffer/FTSH-105-01-F-DV-K.step.SLDASM
hw/UWBkit_minimal/UWBkit_minimal.SLDASM
hw/UWBkit_minimal/case.3mf
hw/UWBkit_minimal/case.STL
hw/UWBkit_minimal/lid.STL
hw/UWBkit_minimal/lid_oled.STL
hw/UWBkit_minimal/oled_holder.STL
hw/UWBkit_sniffer/case_bottom.STL
hw/UWBkit_sniffer/case_lid.STL

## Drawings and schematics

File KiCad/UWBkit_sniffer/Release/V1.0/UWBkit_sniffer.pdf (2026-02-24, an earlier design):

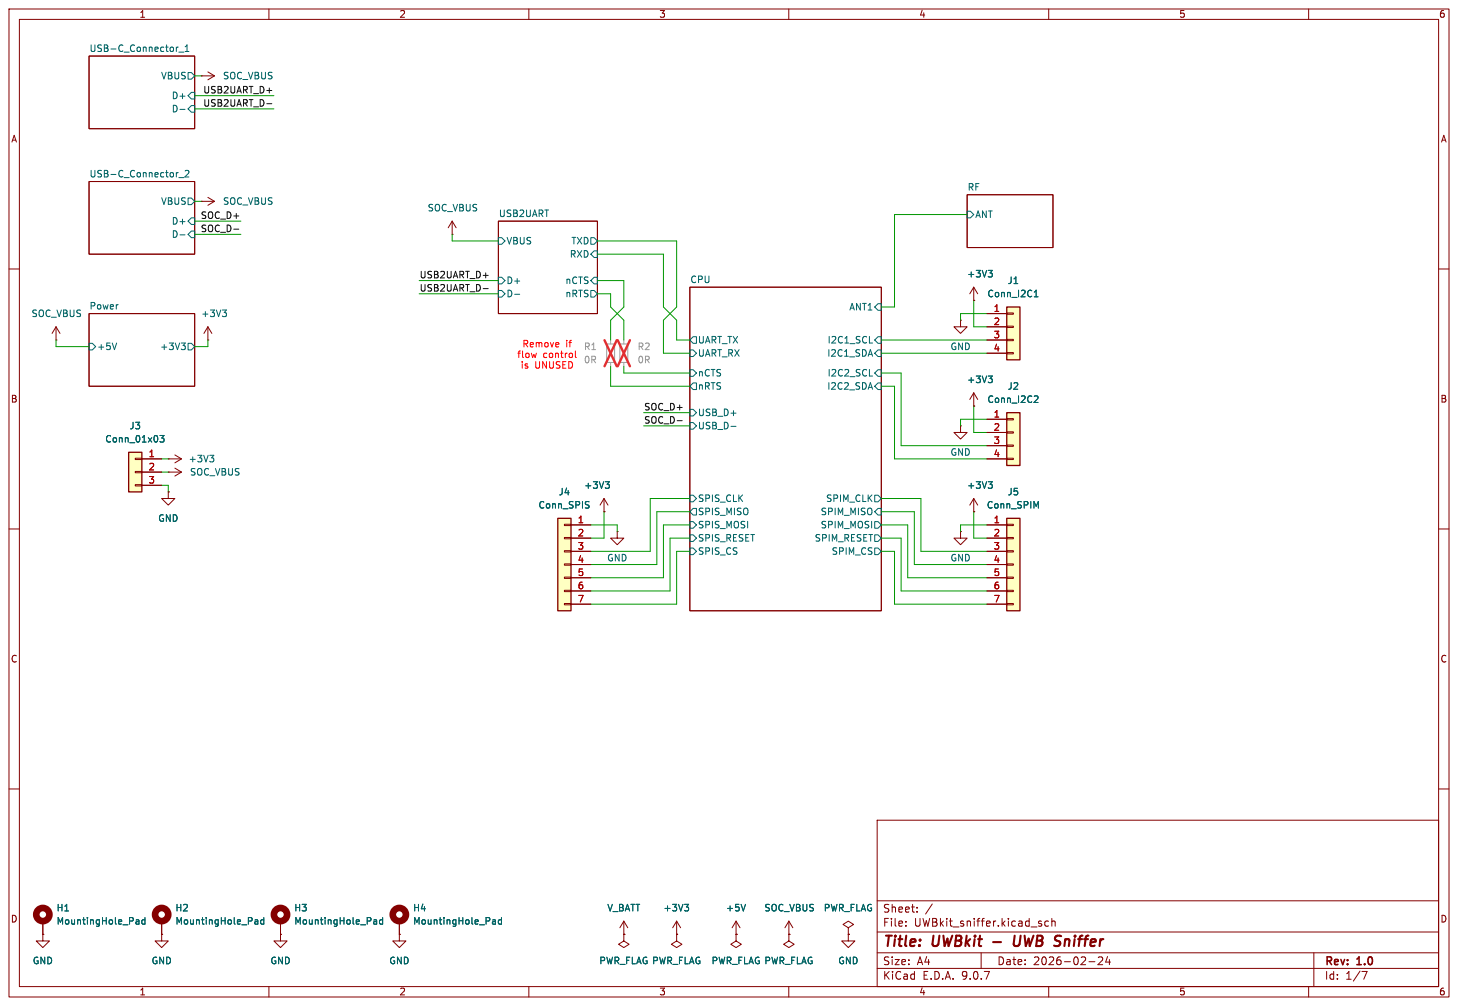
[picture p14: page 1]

Id: 1/7 Title: UWBkit - UWB Sniffer File: UWBkit_sniffer.kicad_sch Sheet: /

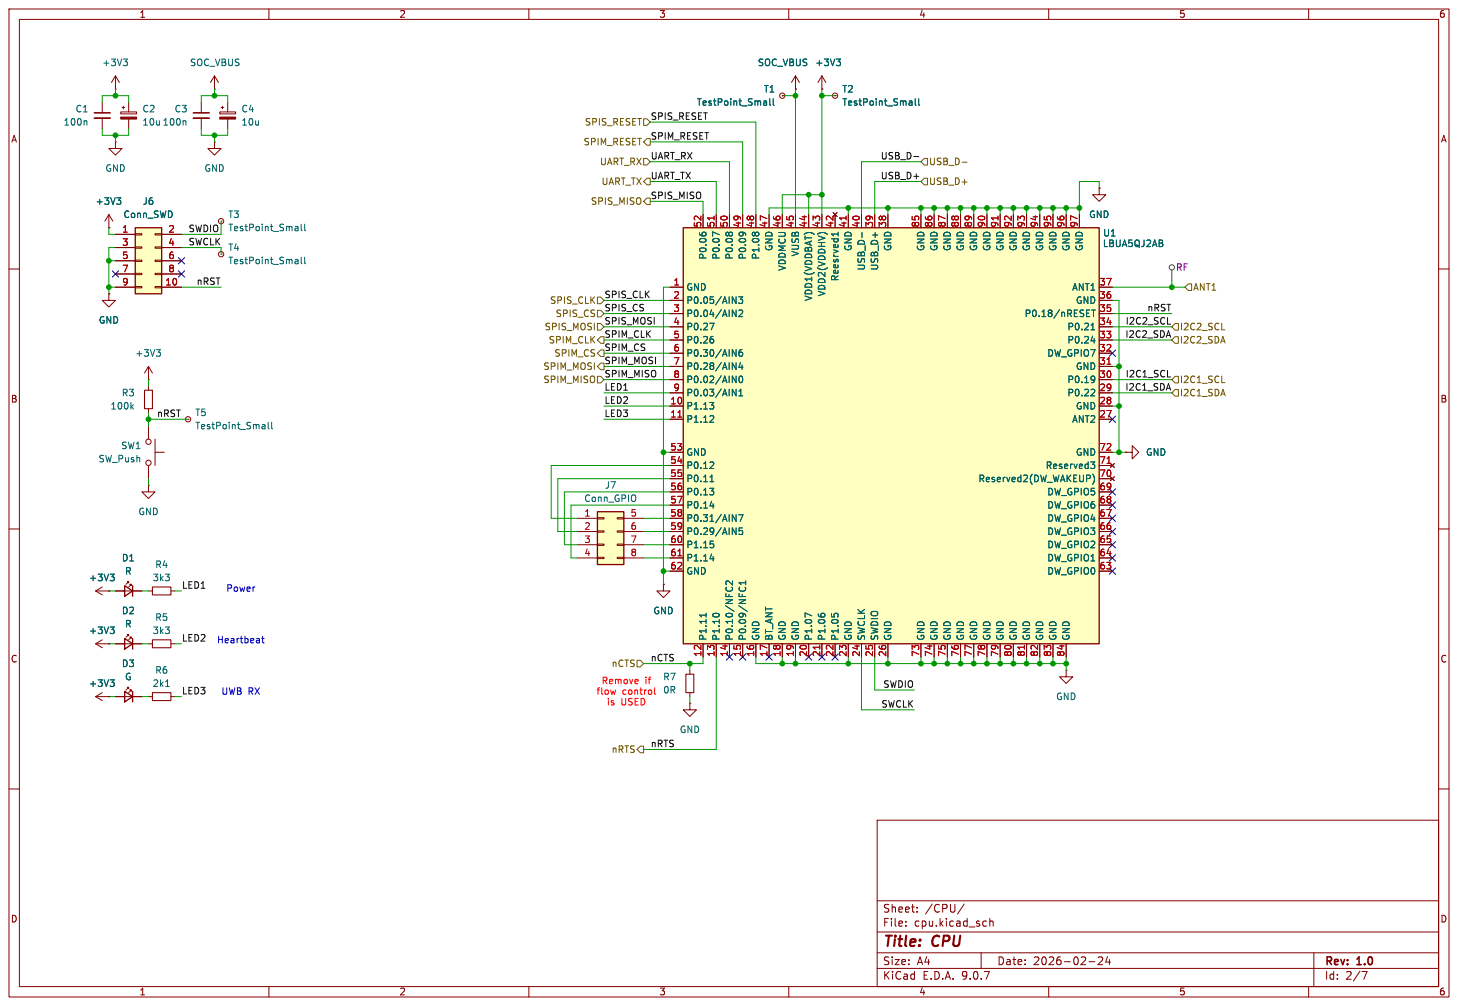
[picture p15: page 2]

File: cpu.kicad_sch Sheet: /CPU/
Id: 2/7 Title: CPU

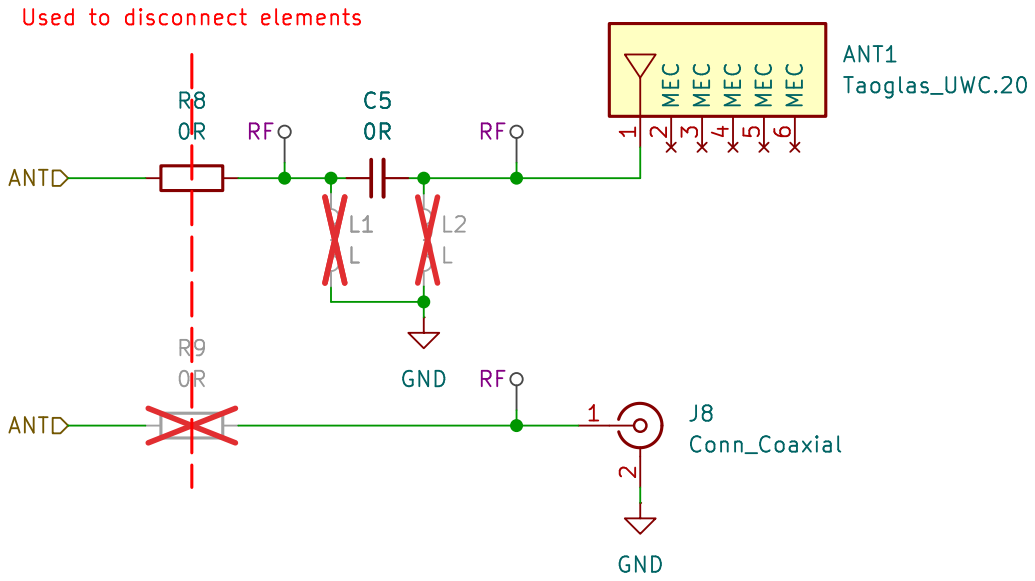
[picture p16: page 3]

File: rf.kicad_sch Sheet: /RF/
Id: 3/7 Title: RF

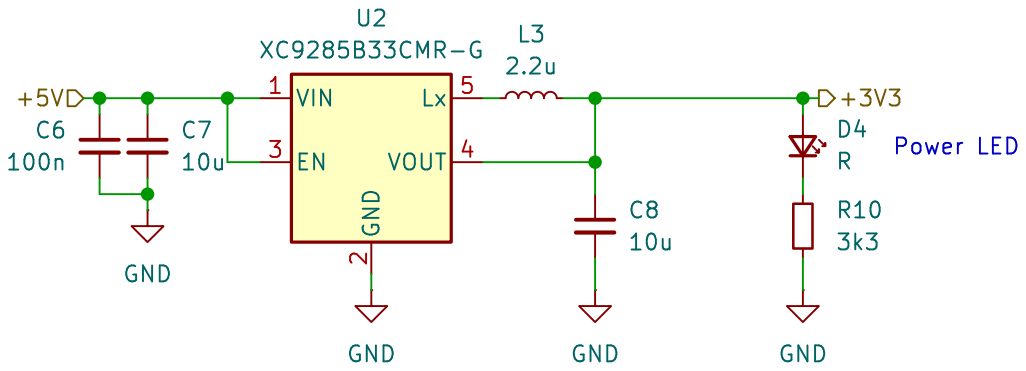
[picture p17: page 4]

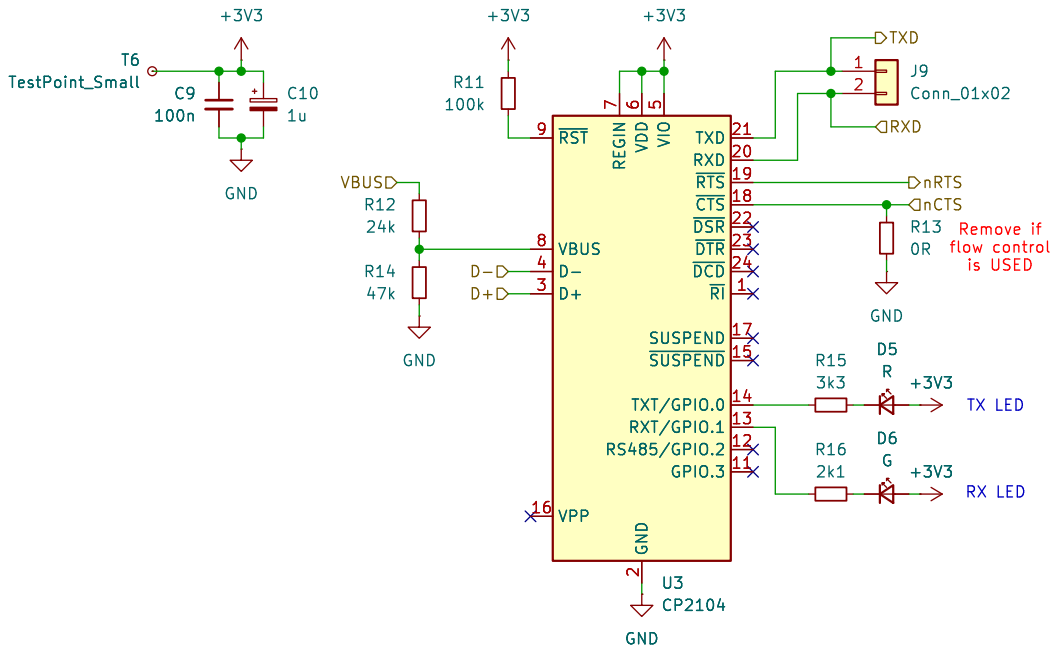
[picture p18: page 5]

5 TXD 21 RXD 20 ~{RTS} 19 ~{CTS} 18 ~{DSR} 22 ~{DTR} 23 ~{DCD} 24 ~{RI}1 SUSPEND 17 ~{SUSPEND}15 TXT/GPIO.0 14 RXT/GPIO.1 13 RS485/GPIO.2 12 GPIO.3 11 U3 CP2104 GND

5 TXD 21 RXD 20 ~{RTS} 19 ~{CTS} 18 ~{DSR} 22 ~{DTR} 23 ~{DCD} 24 ~{RI}1 SUSPEND 17 ~{SUSPEND}15 TXT/GPIO.0 14 RXT/GPIO.1 13 RS485/GPIO.2 12 GPIO.3 11 GND

File: usb_uart_bridge.kicad_sch Sheet: /USB2UART/
Id: 5/7 Title: USB to UART Bridge

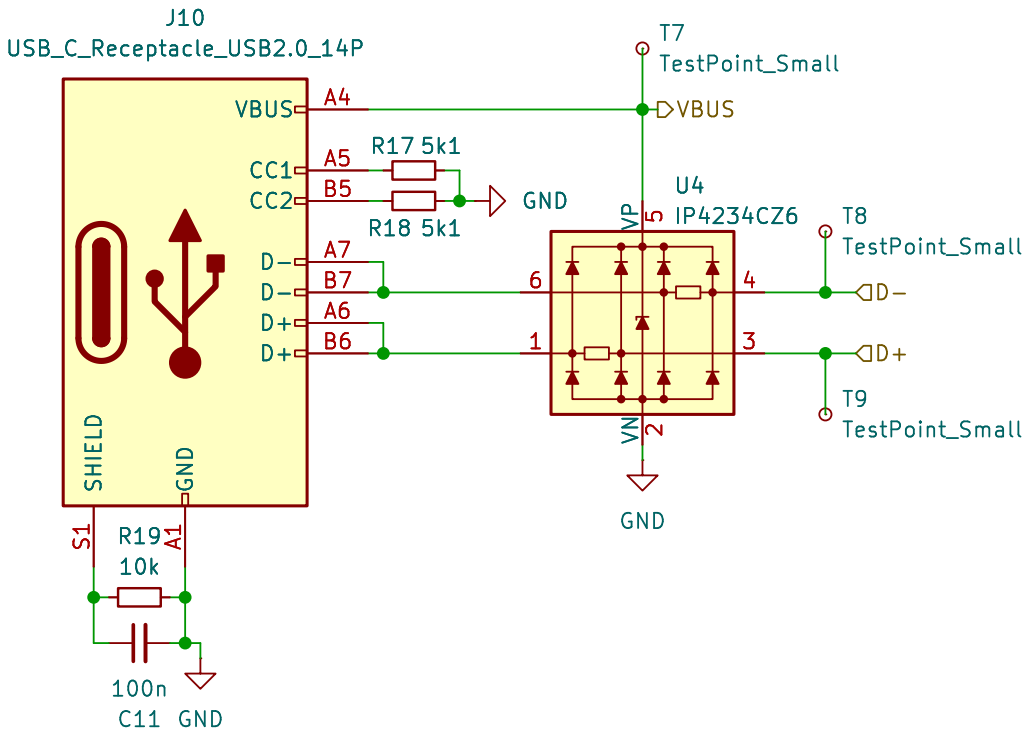
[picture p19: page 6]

Id: 6/7 Title: USB Typer C Connector File: usb_c.kicad_sch Sheet: /USB-C_Connector_1/

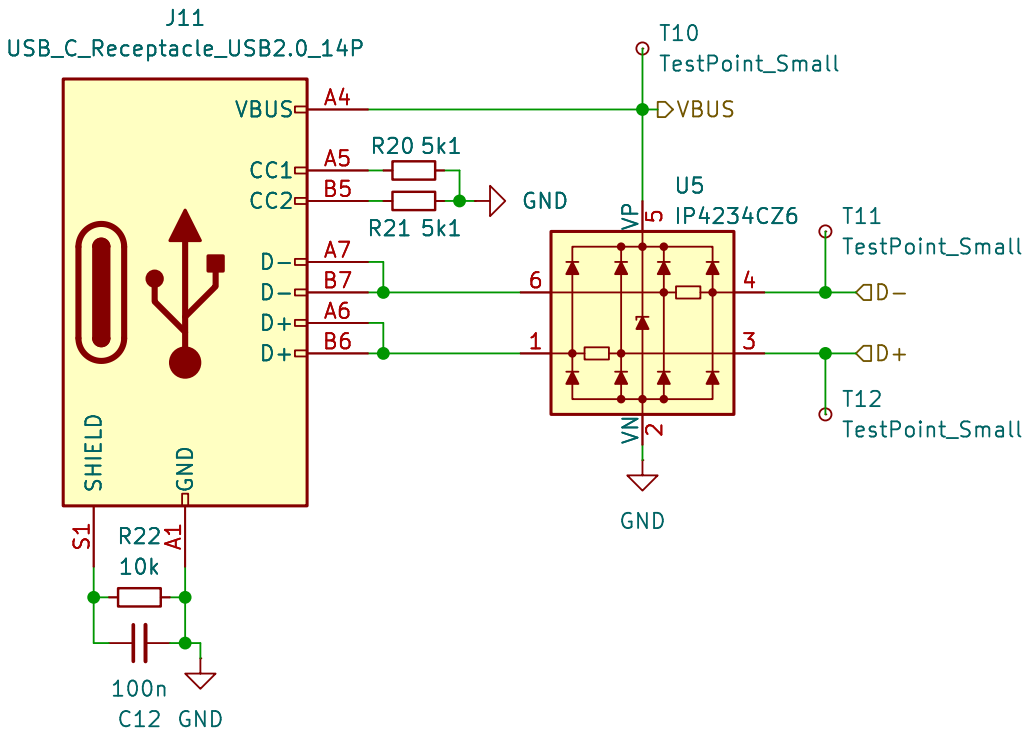
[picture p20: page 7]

Id: 7/7 Title: USB Typer C Connector File: usb_c.kicad_sch Sheet: /USB-C_Connector_2/

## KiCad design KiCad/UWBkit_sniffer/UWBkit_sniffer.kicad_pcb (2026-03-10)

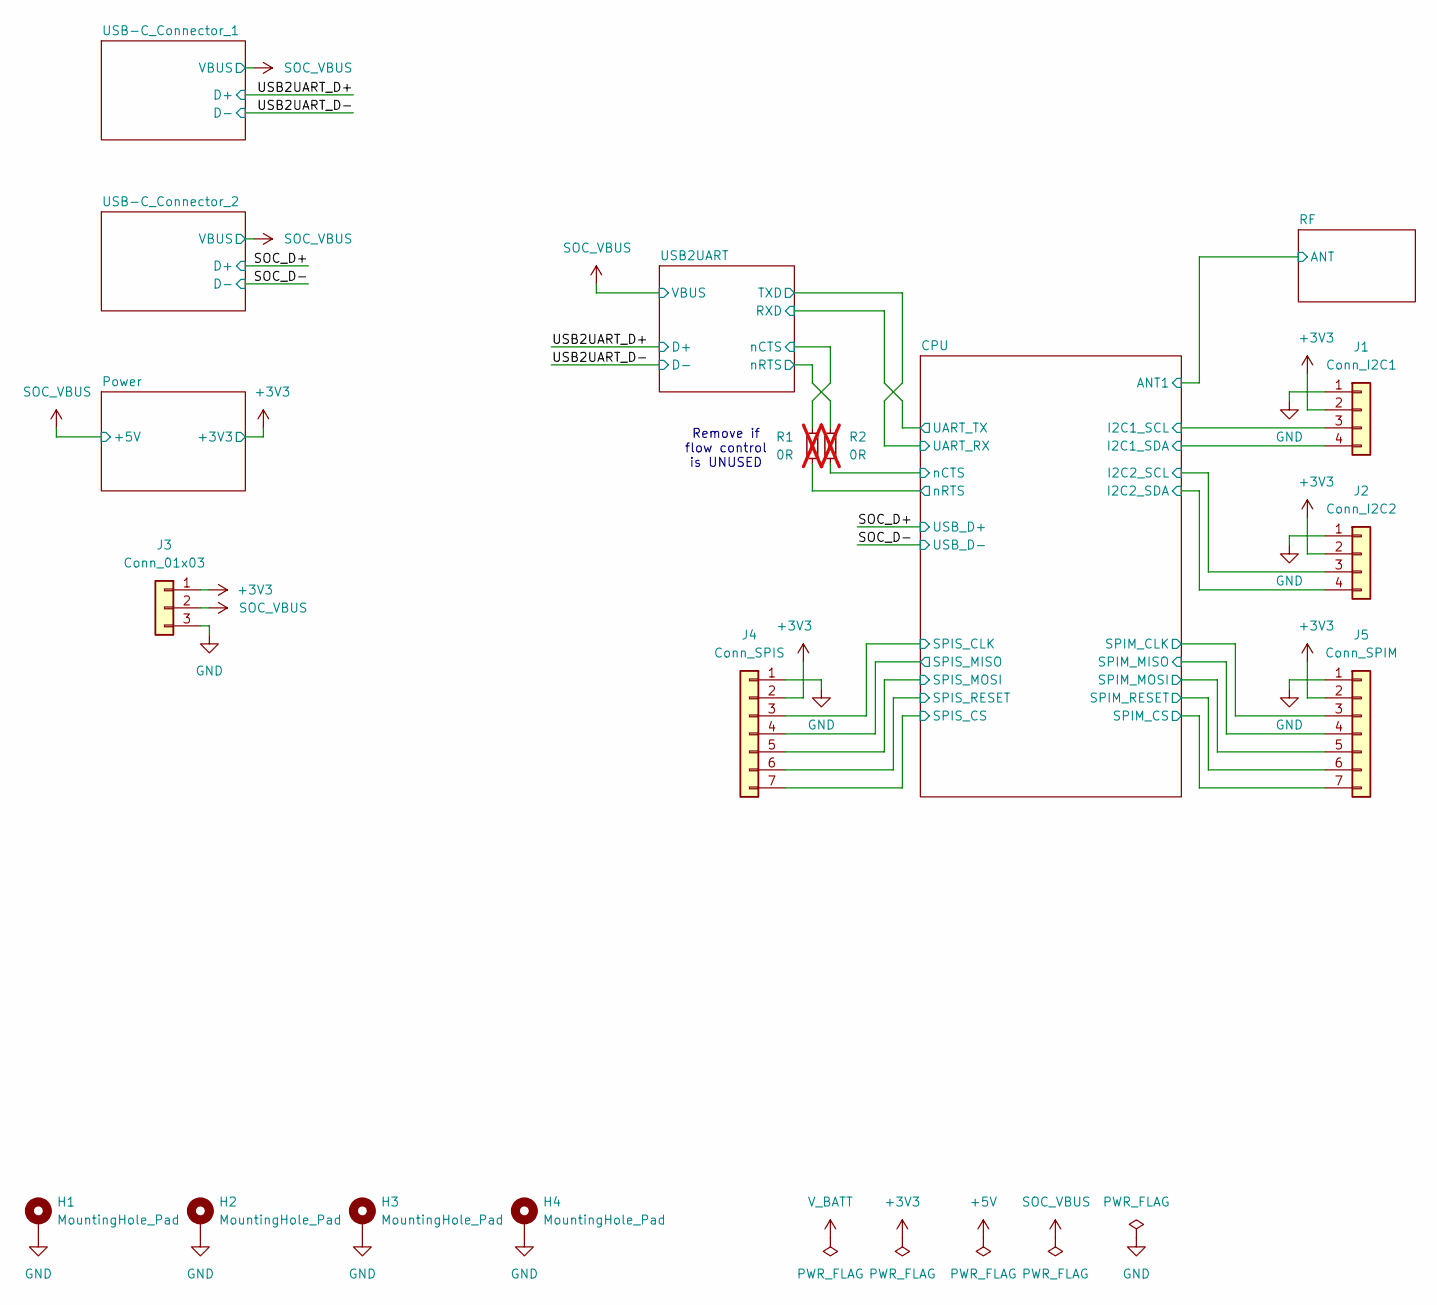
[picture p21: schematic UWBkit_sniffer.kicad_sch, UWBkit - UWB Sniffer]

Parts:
H1, H2, H3, H4: MountingHole_Pad; MountingHole_3.2mm_M3_Pad_Via
J1: Conn_I2C1; PinSocket_1x04_P2.54mm_Vertical
J2: Conn_I2C2; PinSocket_1x04_P2.54mm_Vertical
J3: Conn_01x03; PinSocket_1x03_P2.54mm_Vertical
J4: Conn_SPIS; PinSocket_1x07_P2.54mm_Vertical
J5: Conn_SPIM; PinSocket_1x07_P2.54mm_Vertical
R1, R2: 0R; R_0603_1608Metric; not fitted

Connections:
+3V3: J1.2, J2.2, J3.1, J4.2, J5.2; also elsewhere on the board
/CPU/I2C1_SCL: J1.3; also elsewhere on the board
/CPU/I2C1_SDA: J1.4; also elsewhere on the board
/CPU/I2C2_SCL: J2.3; also elsewhere on the board
/CPU/I2C2_SDA: J2.4; also elsewhere on the board
/CPU/SPIM_CLK: J5.3; also elsewhere on the board
/CPU/SPIM_CS: J5.7; also elsewhere on the board
/CPU/SPIM_MISO: J5.4; also elsewhere on the board
/CPU/SPIM_MOSI: J5.5; also elsewhere on the board
/CPU/SPIM_RESET: J5.6; also elsewhere on the board
/CPU/SPIS_CLK: J4.3; also elsewhere on the board
/CPU/SPIS_CS: J4.7; also elsewhere on the board
/CPU/SPIS_MISO: J4.4; also elsewhere on the board
/CPU/SPIS_MOSI: J4.5; also elsewhere on the board
/CPU/SPIS_RESET: J4.6; also elsewhere on the board
/CPU/nCTS: R2.2; also elsewhere on the board
/CPU/nRTS: R1.2; also elsewhere on the board
/USB2UART/nCTS: R1.1; also elsewhere on the board
/USB2UART/nRTS: R2.1; also elsewhere on the board
GND: H1.1, H2.1, H3.1, H4.1, J1.1, J2.1, J3.3, J4.1, J5.1; also elsewhere on the board
SOC_VBUS: J3.2; also elsewhere on the board

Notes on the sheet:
Remove if flow control is UNUSED

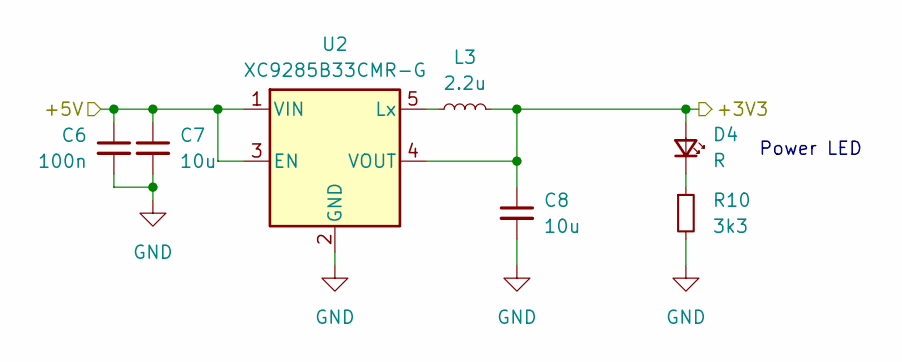
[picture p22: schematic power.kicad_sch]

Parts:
C6: 100n; C_0603_1608Metric
C7, C8: 10u; C_0603_1608Metric
D4: R; LED_0603_1608Metric; Voltage 1.75 V
L3: 2.2u; L_0805_2012Metric
R10: 3k3; R_0603_1608Metric
U2: XC9285B33CMR-G; SOT-23-5

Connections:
+3V3: C8.1, D4.2 (A), L3.2, U2.4 (VOUT); also elsewhere on the board
GND: C6.2, C7.2, C8.2, R10.2, U2.2 (GND); also elsewhere on the board
unnamed: D4.1 (K), R10.1
unnamed: L3.1, U2.5 (Lx)
SOC_VBUS: C6.1, C7.1, U2.1 (VIN), U2.3 (EN); also elsewhere on the board

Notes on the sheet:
Power LED

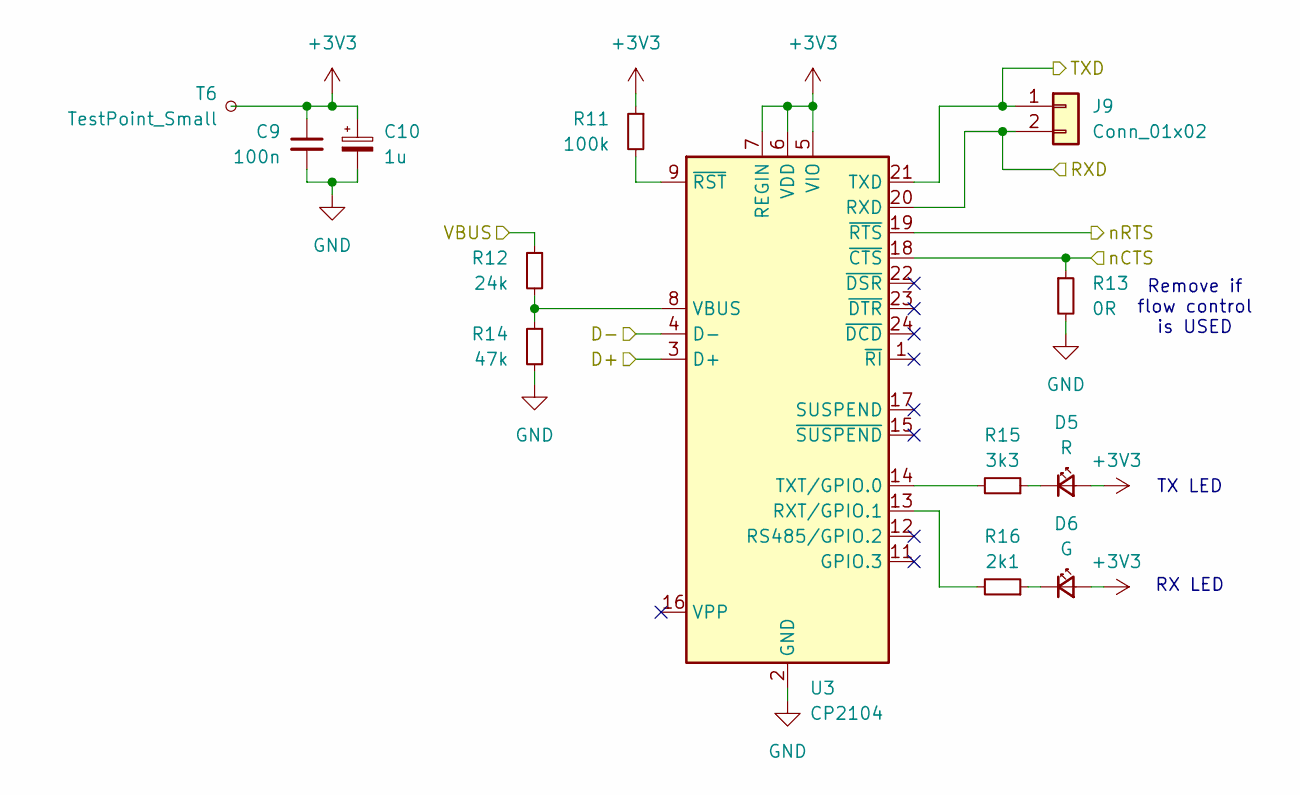
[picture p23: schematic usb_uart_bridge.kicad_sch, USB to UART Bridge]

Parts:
C9: 100n; C_0603_1608Metric
C10: 1u; CP_EIA-3216-18_Kemet-A
D5: R; LED_0603_1608Metric; Voltage 1.75 V
D6: G; LED_0603_1608Metric; Voltage 2.25 V
J9: Conn_01x02; PinHeader_1x02_P2.54mm_Vertical
R11: 100k; R_0603_1608Metric
R12: 24k; R_0603_1608Metric
R13: 0R; R_0603_1608Metric
R14: 47k; R_0603_1608Metric
R15: 3k3; R_0603_1608Metric
R16: 2k1; R_0603_1608Metric
T6: TestPoint_Small; TestPoint_Pad_D1.0mm
U3: CP2104; QFN-24-1EP_4x4mm_P0.5mm_EP2.6x2.6mm

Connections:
+3V3: C9.1, C10.1, D5.2 (A), D6.2 (A), R11.1, T6.1, U3.5 (VIO), U3.6 (VDD), U3.7 (REGIN); also elsewhere on the board
/CPU/UART_RX: J9.1, U3.21 (TXD); also elsewhere on the board
/CPU/UART_TX: J9.2, U3.20 (RXD); also elsewhere on the board
/USB2UART/nCTS: R13.1, U3.18 (~CTS); also elsewhere on the board
/USB2UART/nRTS: U3.19 (~RTS); also elsewhere on the board
/USB2UART_D+: U3.3 (D+); also elsewhere on the board
/USB2UART_D-: U3.4 (D-); also elsewhere on the board
GND: C9.2, C10.2, R13.2, R14.2, U3.2 (GND), U3.25 (GND); also elsewhere on the board
unnamed: D5.1 (K), R15.1
unnamed: D6.1 (K), R16.1
unnamed: R16.2, U3.13 (RXT/GPIO.1)
unnamed: R15.2, U3.14 (TXT/GPIO.0)
unnamed: R12.2, R14.1, U3.8 (VBUS)
unnamed: R11.2, U3.9 (~RST)
SOC_VBUS: R12.1; also elsewhere on the board

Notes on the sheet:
Remove if flow control is USED
TX LED
RX LED

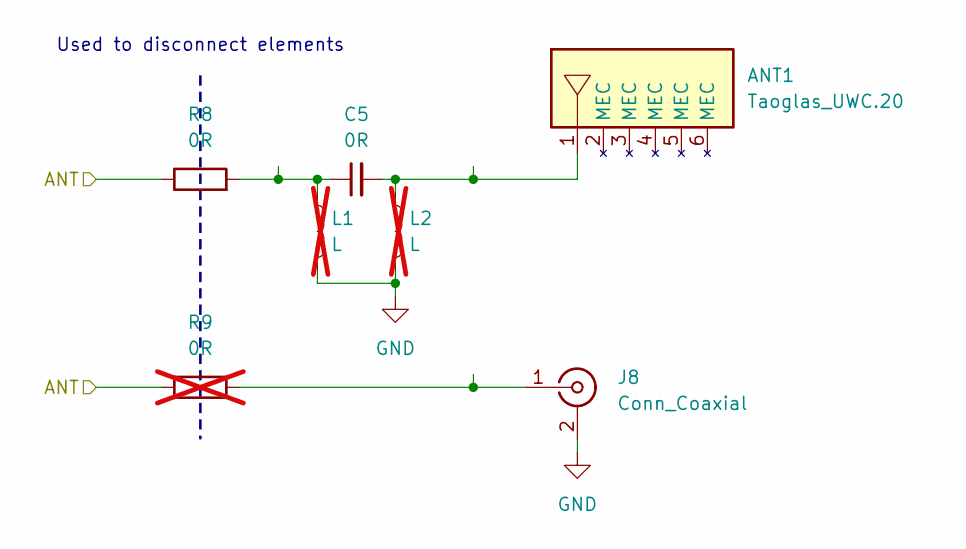
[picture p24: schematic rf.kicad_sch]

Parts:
ANT1: Taoglas_UWC.20
C5: 0R; C_0603_1608Metric
J8: Conn_Coaxial; SMA_Molex_73251-1153_EdgeMount_Horizontal
L1, L2: L; L_0603_1608Metric; not fitted
R8: 0R; R_0603_1608Metric
R9: 0R; R_0603_1608Metric; not fitted

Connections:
/CPU/ANT1: R8.1, R9.1; also elsewhere on the board
GND: J8.2 (Ext), L1.2, L2.2; also elsewhere on the board
unnamed: ANT1.1, C5.2, L2.1
unnamed: C5.1, L1.1, R8.2
unnamed: J8.1 (In), R9.2

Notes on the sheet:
Used to disconnect elements

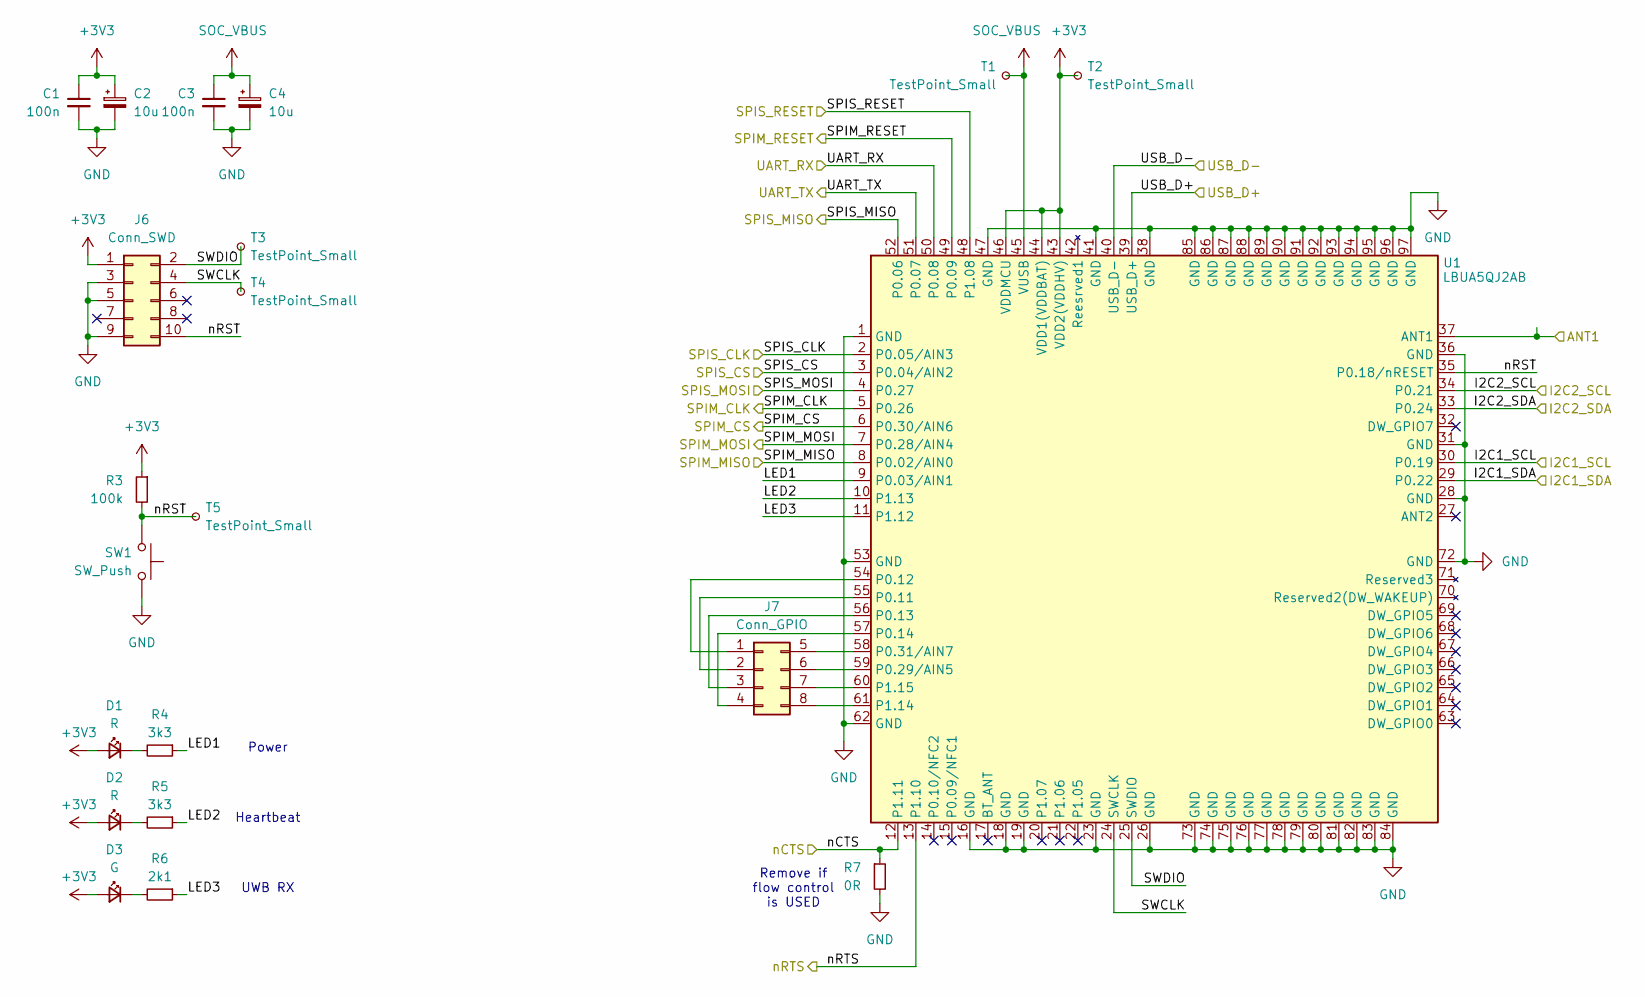
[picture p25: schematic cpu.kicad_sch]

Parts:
C1, C3: 100n; C_0603_1608Metric
C2, C4: 10u; CP_EIA-3216-18_Kemet-A
D1, D2: R; LED_0603_1608Metric; Voltage 1.75 V
D3: G; LED_0603_1608Metric; Voltage 2.25 V
J6: Conn_SWD; PinHeader_2x05_P1.27mm_Vertical_SMD
J7: Conn_GPIO; PinSocket_2x04_P2.54mm_Vertical
R3: 100k; R_0603_1608Metric
R4, R5: 3k3; R_0603_1608Metric
R6: 2k1; R_0603_1608Metric
R7: 0R; R_0603_1608Metric
SW1: SW_Push; SW_TH_Tactile_Omron_B3F-106x
T1, T2, T3, T4, T5: TestPoint_Small; TestPoint_Pad_D1.0mm
U1: LBUA5QJ2AB

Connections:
+3V3: C1.1, C2.1, D1.2 (A), D2.2 (A), D3.2 (A), J6.1, R3.1, T2.1, U1.43 (VDD2(VDDHV)), U1.44 (VDD1(VDDBAT)), U1.46 (VDDMCU); also elsewhere on the board
/CPU/ANT1: U1.37 (ANT1); also elsewhere on the board
/CPU/I2C1_SCL: U1.30 (P0.19); also elsewhere on the board
/CPU/I2C1_SDA: U1.29 (P0.22); also elsewhere on the board
/CPU/I2C2_SCL: U1.34 (P0.21); also elsewhere on the board
/CPU/I2C2_SDA: U1.33 (P0.24); also elsewhere on the board
/CPU/LED1: R4.1, U1.9 (P0.03/AIN1)
/CPU/LED2: R5.1, U1.10 (P1.13)
/CPU/LED3: R6.1, U1.11 (P1.12)
/CPU/SPIM_CLK: U1.5 (P0.26); also elsewhere on the board
/CPU/SPIM_CS: U1.6 (P0.30/AIN6); also elsewhere on the board
/CPU/SPIM_MISO: U1.8 (P0.02/AIN0); also elsewhere on the board
/CPU/SPIM_MOSI: U1.7 (P0.28/AIN4); also elsewhere on the board
/CPU/SPIM_RESET: U1.49 (P0.09); also elsewhere on the board
/CPU/SPIS_CLK: U1.2 (P0.05/AIN3); also elsewhere on the board
/CPU/SPIS_CS: U1.3 (P0.04/AIN2); also elsewhere on the board
/CPU/SPIS_MISO: U1.52 (P0.06); also elsewhere on the board
/CPU/SPIS_MOSI: U1.4 (P0.27); also elsewhere on the board
/CPU/SPIS_RESET: U1.48 (P1.08); also elsewhere on the board
/CPU/SWCLK: J6.4, T4.1, U1.24 (SWCLK)
/CPU/SWDIO: J6.2, T3.1, U1.25 (SWDIO)
/CPU/UART_RX: U1.50 (P0.08); also elsewhere on the board
/CPU/UART_TX: U1.51 (P0.07); also elsewhere on the board
/CPU/nCTS: R7.1, U1.12 (P1.11); also elsewhere on the board
/CPU/nRST: J6.10, R3.2, SW1.2, T5.1, U1.35 (P0.18/nRESET)
/CPU/nRTS: U1.13 (P1.10); also elsewhere on the board
/SOC_D+: U1.39 (USB_D+); also elsewhere on the board
/SOC_D-: U1.40 (USB_D-); also elsewhere on the board
GND: C1.2, C2.2, C3.2, C4.2, J6.3, J6.5, J6.9, R7.2, SW1.1, U1.1 (GND), U1.16 (GND), U1.18 (GND), U1.19 (GND), U1.23 (GND), U1.26 (GND), U1.28 (GND), U1.31 (GND), U1.36 (GND), U1.38 (GND), U1.41 (GND), U1.47 (GND), U1.53 (GND), U1.62 (GND), U1.72 (GND), U1.73 (GND), U1.74 (GND), U1.75 (GND), U1.76 (GND), U1.77 (GND), U1.78 (GND), U1.79 (GND), U1.80 (GND), U1.81 (GND), U1.82 (GND), U1.83 (GND), U1.84 (GND), U1.85 (GND), U1.86 (GND), U1.87 (GND), U1.88 (GND), U1.89 (GND), U1.90 (GND), U1.91 (GND), U1.92 (GND), U1.93 (GND), U1.94 (GND), U1.95 (GND), U1.96 (GND), U1.97 (GND); also elsewhere on the board
unnamed: D1.1 (K), R4.2
unnamed: D2.1 (K), R5.2
unnamed: D3.1 (K), R6.2
unnamed: J7.1, U1.54 (P0.12)
unnamed: J7.2, U1.55 (P0.11)
unnamed: J7.3, U1.56 (P0.13)
unnamed: J7.4, U1.57 (P0.14)
unnamed: J7.5, U1.58 (P0.31/AIN7)
unnamed: J7.6, U1.59 (P0.29/AIN5)
unnamed: J7.7, U1.60 (P1.15)
unnamed: J7.8, U1.61 (P1.14)
SOC_VBUS: C3.1, C4.1, T1.1, U1.45 (VUSB); also elsewhere on the board

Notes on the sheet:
Power
Heartbeat
Remove if flow control is USED
UWB RX

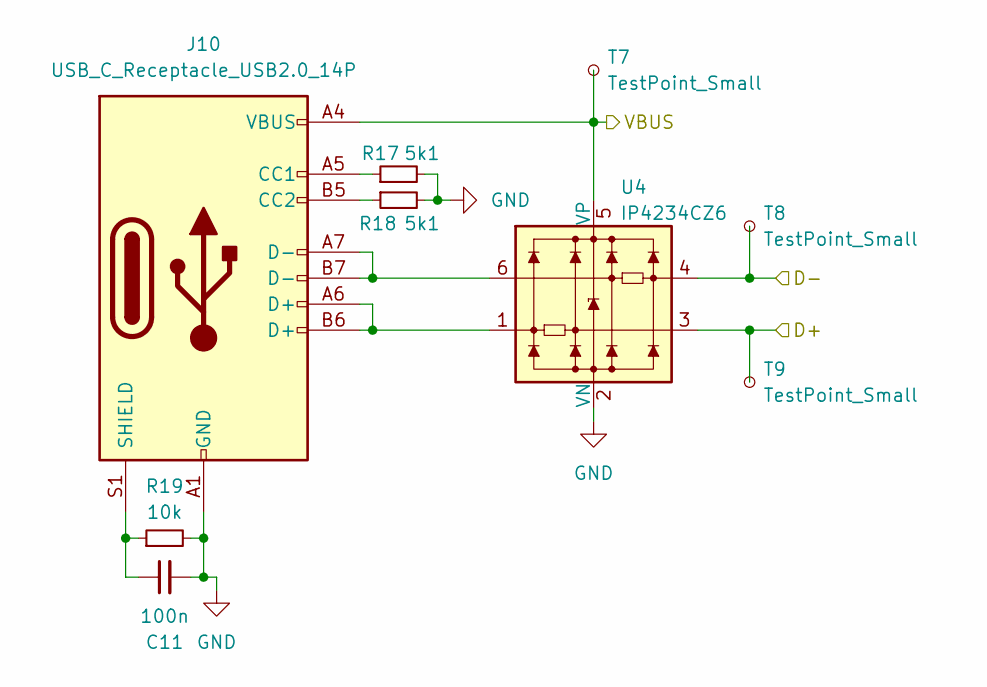
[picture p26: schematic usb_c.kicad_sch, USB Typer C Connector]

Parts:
C11: 100n; C_0603_1608Metric
J10: USB_C_Receptacle_USB2.0_14P; USB_C_Receptacle_GCT_USB4105-xx-A_16P_TopMnt_Horizontal
R17, R18: 5k1; R_0603_1608Metric
R19: 10k; R_0603_1608Metric
T7, T8, T9: TestPoint_Small; TestPoint_Pad_D1.0mm
U4: IP4234CZ6; SC-74-6_1.55x2.9mm_P0.95mm

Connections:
/USB2UART_D+: T9.1, U4.3; also elsewhere on the board
/USB2UART_D-: T8.1, U4.4; also elsewhere on the board
GND: C11.2, J10.A1 (GND), J10.A12 (GND), J10.B1 (GND), J10.B12 (GND), R17.2, R18.2, R19.2, U4.2 (VN); also elsewhere on the board
unnamed: J10.A5 (CC1), R17.1
unnamed: J10.B5 (CC2), R18.1
unnamed: J10.A6 (D+), J10.B6 (D+), U4.1
unnamed: J10.A7 (D-), J10.B7 (D-), U4.6
unnamed: C11.1, J10.S1 (SHIELD), R19.1
SOC_VBUS: J10.A4 (VBUS), J10.A9 (VBUS), J10.B4 (VBUS), J10.B9 (VBUS), T7.1, U4.5 (VP); also elsewhere on the board

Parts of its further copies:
C12: 100n; C_0603_1608Metric
J11: USB_C_Receptacle_USB2.0_14P; USB_C_Receptacle_GCT_USB4105-xx-A_16P_TopMnt_Horizontal
R20, R21: 5k1; R_0603_1608Metric
R22: 10k; R_0603_1608Metric
T10, T11, T12: TestPoint_Small; TestPoint_Pad_D1.0mm
U5: IP4234CZ6; SC-74-6_1.55x2.9mm_P0.95mm

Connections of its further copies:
/SOC_D+: T12.1, U5.3; also elsewhere on the board
/SOC_D-: T11.1, U5.4; also elsewhere on the board
GND: C12.2, J11.A1 (GND), J11.A12 (GND), J11.B1 (GND), J11.B12 (GND), R20.2, R21.2, R22.2, U5.2 (VN); also elsewhere on the board
unnamed: J11.A5 (CC1), R20.1
unnamed: J11.B5 (CC2), R21.1
unnamed: J11.A6 (D+), J11.B6 (D+), U5.1
unnamed: J11.A7 (D-), J11.B7 (D-), U5.6
unnamed: C12.1, J11.S1 (SHIELD), R22.1
SOC_VBUS: J11.A4 (VBUS), J11.A9 (VBUS), J11.B4 (VBUS), J11.B9 (VBUS), T10.1, U5.5 (VP); also elsewhere on the board

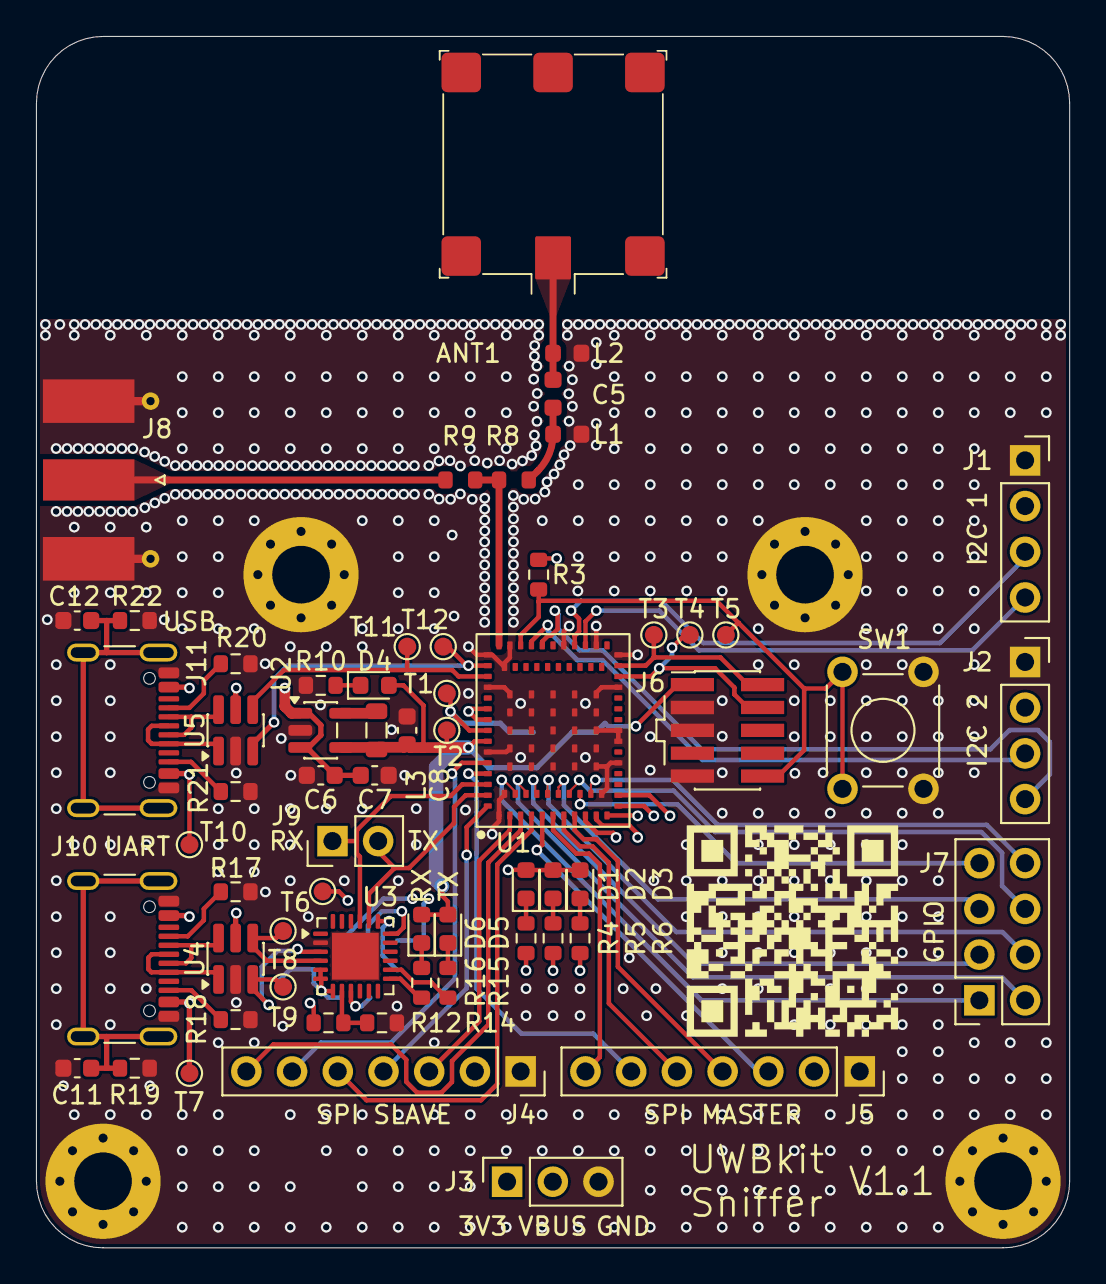
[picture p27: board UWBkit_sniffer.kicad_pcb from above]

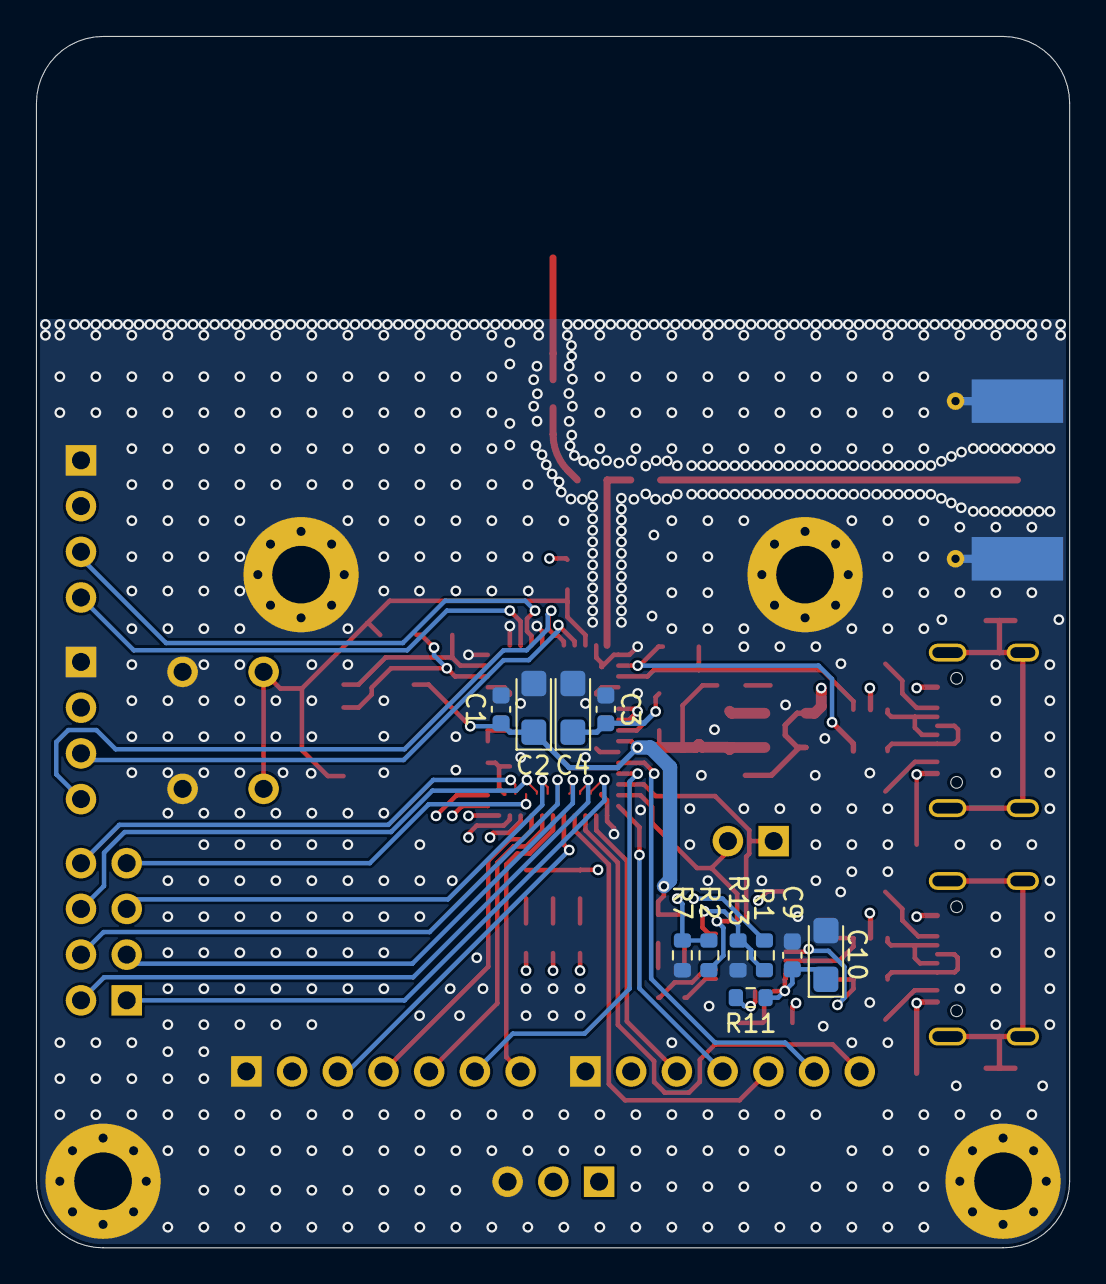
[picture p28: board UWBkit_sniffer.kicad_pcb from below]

Board: 4 copper layers, 57.4 x 67.3 mm, 78 parts (11 on the bottom side), 66 nets.

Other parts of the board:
QR*****: https://github.com/GraniteGobbler/UWBkit; Git-Repo-QR

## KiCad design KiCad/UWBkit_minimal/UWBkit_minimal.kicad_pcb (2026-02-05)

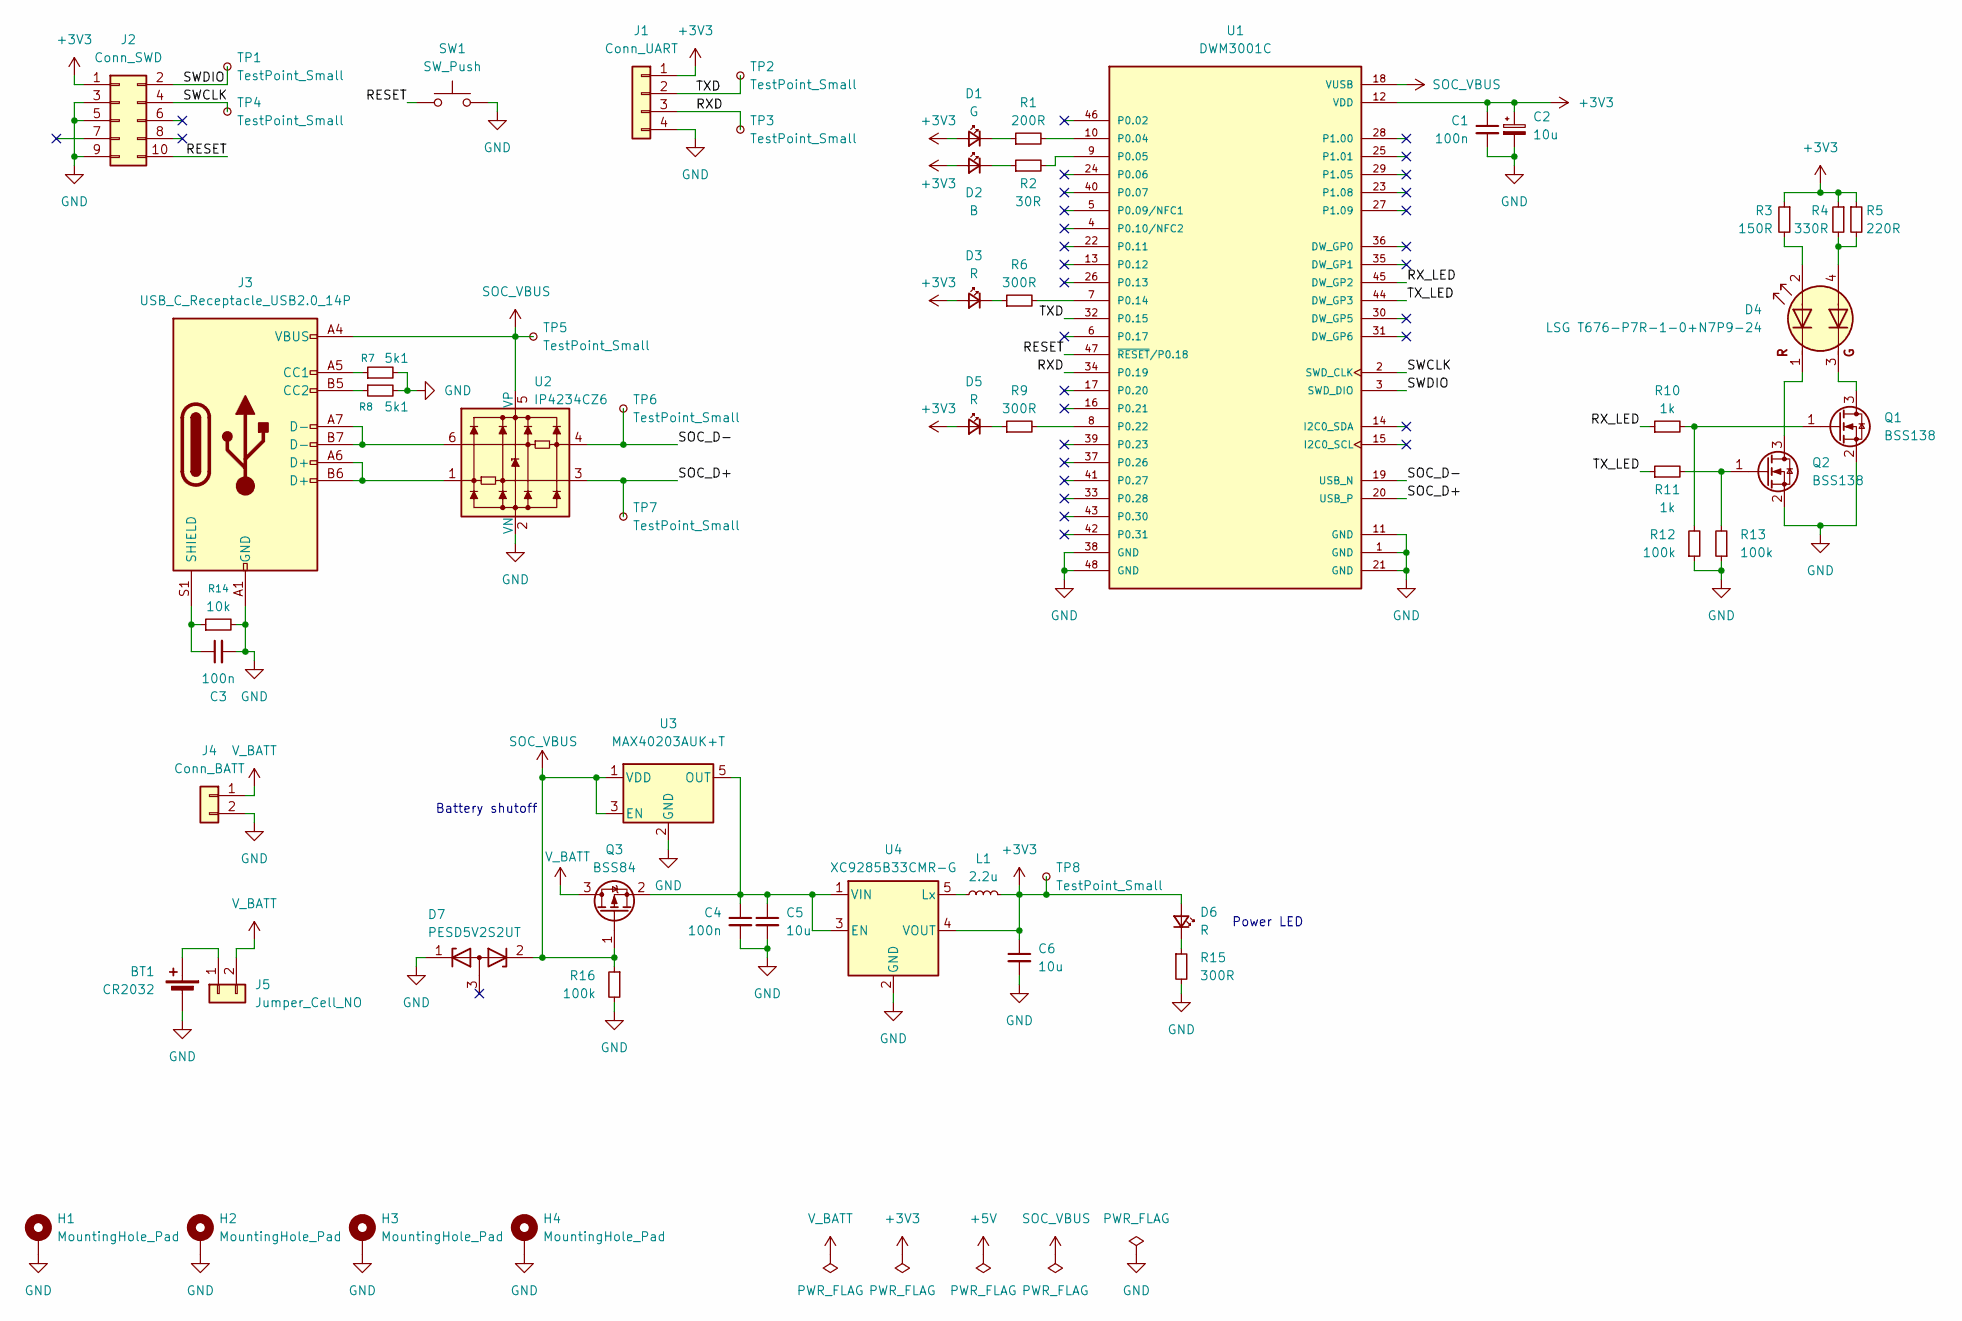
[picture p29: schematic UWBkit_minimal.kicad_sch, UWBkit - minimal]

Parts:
BT1: CR2032; BatteryHolder_Keystone_1058_1x2032
C1, C3, C4: 100n; C_0603_1608Metric
C2: 10u; CP_EIA-3216-18_Kemet-A
C5, C6: 10u; C_0603_1608Metric
D1: G; LED_0603_1608Metric
D2: B; LED_0603_1608Metric
D3, D5, D6: R; LED_0603_1608Metric
D4: LSG T676-P7R-1-0+N7P9-24; LED_Dual_OSRAM-PLCC4_3.2x2.8mm
D7: PESD5V2S2UT; SOT-23
H1, H2, H3, H4: MountingHole_Pad; MountingHole_3.2mm_M3_ISO14580_Pad_TopBottom
J1: Conn_UART; PinSocket_1x04_P2.54mm_Vertical
J2: Conn_SWD; PinHeader_2x05_P1.27mm_Vertical_SMD
J3: USB_C_Receptacle_USB2.0_14P; USB_C_Receptacle_GCT_USB4105-xx-A_16P_TopMnt_Horizontal
J4: Conn_BATT; PinSocket_1x02_P2.54mm_Vertical
J5: Jumper_Cell_NO; PinHeader_1x02_P2.54mm_Vertical
L1: 2.2u; L_0805_2012Metric
Q1, Q2: BSS138; SOT-23
Q3: BSS84; SOT-23-3
R1: 200R; R_0603_1608Metric
R2: 30R; R_0603_1608Metric
R3: 150R; R_0603_1608Metric
R4: 330R; R_0603_1608Metric
R5: 220R; R_0603_1608Metric
R6, R9, R15: 300R; R_0603_1608Metric
R7, R8: 5k1; R_0603_1608Metric
R10, R11: 1k; R_0603_1608Metric
R12, R13, R16: 100k; R_0603_1608Metric
R14: 10k; R_0603_1608Metric
SW1: SW_Push; SW_TH_Tactile_Omron_B3F-106x
TP1, TP4: TestPoint_Small; TestPoint_Pad_D1.5mm
TP2, TP3, TP5, TP6, TP7, TP8: TestPoint_Small; TestPoint_Pad_D1.0mm
U1: DWM3001C; PARTREV Rev C
U2: IP4234CZ6; SC-74-6_1.55x2.9mm_P0.95mm
U3: MAX40203AUK+T; SOT-23-5
U4: XC9285B33CMR-G; SOT-23-5

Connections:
+3V3: C1.1, C2.1, C6.1, D1.2 (A), D2.2 (A), D3.2 (A), D5.2 (A), D6.2 (A), J1.1, J2.1, L1.2, R3.1, R4.1, R5.1, TP8.1, U1.12 (VDD), U4.4 (VOUT)
/RESET: J2.10, SW1.2, U1.47 (~RESET/P0.18)
/RXD: J1.3, TP3.1, U1.34 (P0.19)
/RX_LED: R10.1, U1.45 (DW_GP2)
/SOC_D+: TP7.1, U1.20 (USB_P), U2.3
/SOC_D-: TP6.1, U1.19 (USB_N), U2.4
/SWCLK: J2.4, TP4.1, U1.2 (SWD_CLK)
/SWDIO: J2.2, TP1.1, U1.3 (SWD_DIO)
/TXD: J1.2, TP2.1, U1.32 (P0.15)
/TX_LED: R11.1, U1.44 (DW_GP3)
GND: BT1.2 (-), C1.2, C2.2, C3.2, C4.2, C5.2, C6.2, D7.1 (K), H1.1, H2.1, H3.1, H4.1, J1.4, J2.3, J2.5, J2.9, J3.A1 (GND), J3.A12 (GND), J3.B1 (GND), J3.B12 (GND), J4.2, Q1.2 (S), Q2.2 (S), R7.2, R8.2, R12.1, R13.1, R14.2, R15.2, R16.2, SW1.1, U1.1 (GND), U1.11 (GND), U1.21 (GND), U1.38 (GND), U1.48 (GND), U2.2 (VN), U3.2 (GND), U4.2 (GND)
unnamed: BT1.1 (+), J5.1
unnamed: D1.1 (K), R1.1
unnamed: D2.1 (K), R2.1
unnamed: D3.1 (K), R6.1
unnamed: D4.2 (A1), R3.2
unnamed: D4.4 (A2), R4.2, R5.2
unnamed: D4.1 (K1), Q2.3 (D)
unnamed: D4.3 (K2), Q1.3 (D)
unnamed: D5.1 (K), R9.1
unnamed: D6.1 (K), R15.1
unnamed: J3.A5 (CC1), R7.1
unnamed: J3.B5 (CC2), R8.1
unnamed: J3.A6 (D+), J3.B6 (D+), U2.1
unnamed: J3.A7 (D-), J3.B7 (D-), U2.6
unnamed: C3.1, J3.S1 (SHIELD), R14.1
unnamed: Q1.1 (G), R10.2, R12.2
unnamed: Q2.1 (G), R11.2, R13.2
unnamed: C4.1, C5.1, Q3.2 (S), U3.5 (OUT), U4.1 (VIN), U4.3 (EN)
unnamed: R1.2, U1.10 (P0.04)
unnamed: R2.2, U1.9 (P0.05)
unnamed: R6.2, U1.7 (P0.14)
unnamed: R9.2, U1.8 (P0.22)
unnamed: L1.1, U4.5 (Lx)
SOC_VBUS: D7.2 (K), J3.A4 (VBUS), J3.A9 (VBUS), J3.B4 (VBUS), J3.B9 (VBUS), Q3.1 (G), R16.1, TP5.1, U1.18 (VUSB), U2.5 (VP), U3.1 (VDD), U3.3 (EN)
V_BATT: J4.1, J5.2, Q3.3 (D)

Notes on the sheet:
Battery shutoff
Power LED

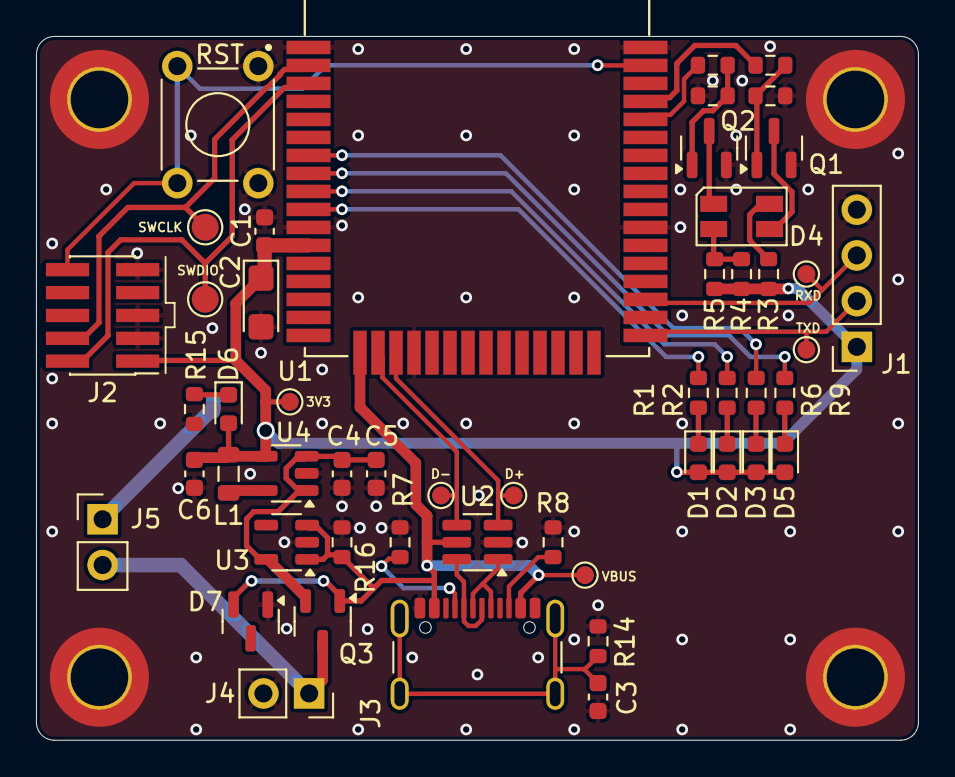
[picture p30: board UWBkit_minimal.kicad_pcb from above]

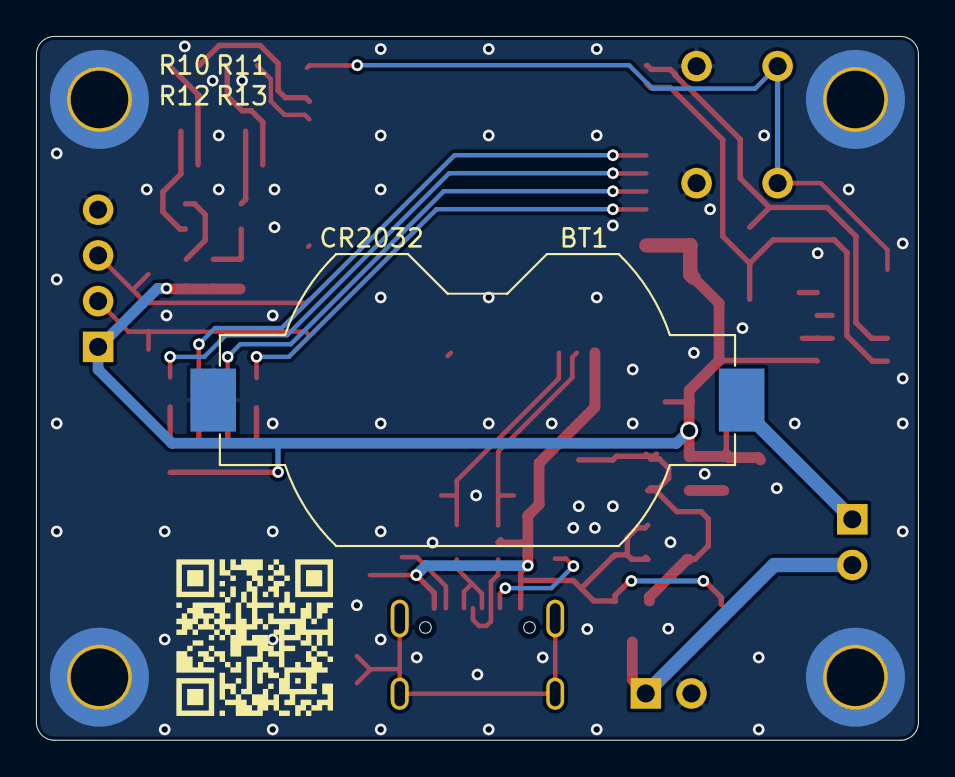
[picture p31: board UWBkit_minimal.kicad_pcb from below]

Board: 2 copper layers, 49.0 x 39.1 mm, 57 parts (2 on the bottom side), 36 nets.

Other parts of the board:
QR*****: Git_QR

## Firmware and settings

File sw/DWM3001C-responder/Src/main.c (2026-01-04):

/*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
-------------------------- END-OF-HEADER -----------------------------

File    : main.c
Purpose : DWM3001C build main entry point for simple exmaples.

*/

#include <boards.h>
#include <deca_spi.h>
#include <port.h>
#include <sdk_config.h>
#include <stdio.h>
#include <stdlib.h>
#include <assert.h>

#include "SSD1306.h"

/* Extern declaration of string buffer */
extern char dist_str[16];

/*! ------------------------------------------------------------------------------------------------------------------
 * @fn test_run_info()
 *
 * @brief  This function is simply a printf() call for a string. It is implemented differently on other platforms,
 *         but on the DWM3001C, a printf() call is .
 *
 * @param data - Message data, this data should be NULL string.
 *
 * output parameters
 *
 * no return value
 */
void test_run_info(unsigned char *data)
{
    printf("%s\n", data);
}

/* 
 * Tick counter used for non-blocking statements
 */
#define DISPLAY_PERIOD_MS  (2000)
volatile uint32_t system_ms = 0;

void SysTick_Handler(void) {
  system_ms++;
}

uint32_t nrf_GetTick(void) {
  return system_ms;
}
/* Non-blocking distance readout */
void display_distance_readout(double dist){
    static uint32_t display_counter = 0;
    if (nrf_GetTick() > display_counter + DISPLAY_PERIOD_MS)
    {
        ssd1306_fill_rect(0, 16, 127, 48, BLACK);
        ssd1306_set_cursor(15, 30);

        sprintf(dist_str, "%3.2f m", dist);
        ssd1306_putstring(dist_str);
        ssd1306_display();

        display_counter = nrf_GetTick();
    }
}

int main(void)
{
    /* Initialize all configured peripherals */
    bsp_board_init(BSP_INIT_LEDS | BSP_INIT_BUTTONS);

    /* Initialise DWM3001C GPIOs */
    gpio_init();

    /* Initialise the SPI for DWM3001C */
    dwm3001c_spi_init();

    /* Configuring interrupt*/
    dw_irq_init();

    /* Small pause before startup */
    nrf_delay_ms(2);

    /* Enable System Tick interrupts */
    SysTick_Config(SystemCoreClock / 1000);

    /* Initialize OLED */
    ssd1306_init_i2c(15, 19);
    ssd1306_begin(0, 0x3C, 1);
    // ssd1306_display();
    ssd1306_set_textsize(2);
    ssd1306_set_textcolor(WHITE);

    // nrf_delay_ms(2000);

    ssd1306_clear_display();
    ssd1306_set_cursor(15, 0);
    ssd1306_puts("Distance");
    // ssd1306_display();

    ssd1306_set_cursor(0, 30);
    ssd1306_putstring("----------");
    ssd1306_display();

    // UNCOMMENT EXACTLY ONE OF THE BELOW EXAMPLES, AND ALSO UNCOMMENT THE CORRESPONDING #define IN example_selection.h:
    // extern int read_dev_id(void); read_dev_id();
    // extern int simple_tx(void); simple_tx();
    // extern int simple_tx_pdoa(void); simple_tx_pdoa();
    // extern int simple_rx(void); simple_rx();
    // extern int simple_rx_nlos(void); simple_rx_nlos();
    // extern int rx_sniff(void); rx_sniff();
    // extern int rx_with_xtal_trim(void); rx_with_xtal_trim();
    // extern int rx_diagnostics(void); rx_diagnostics();
    // extern int tx_sleep(void); tx_sleep();
    // extern int tx_sleep_idleRC(void); tx_sleep_idleRC();
    // extern int tx_timed_sleep(void); tx_timed_sleep();
    // extern int tx_sleep_auto(void); tx_sleep_auto();
    // extern int tx_with_cca(void); tx_with_cca();
    // extern int simple_tx_aes(void); simple_tx_aes();
    // extern int simple_rx_aes(void); simple_rx_aes();
    // extern int tx_wait_resp(void); tx_wait_resp();
    // extern int tx_wait_resp_int(void); tx_wait_resp_int();
    // extern int rx_send_resp(void); rx_send_resp();
    // extern int ss_twr_responder(void); ss_twr_responder();
    // extern int ss_twr_initiator(void); ss_twr_initiator();
    // extern int ss_twr_initiator_sts(void); ss_twr_initiator_sts();
    // extern int ss_twr_responder_sts(void); ss_twr_responder_sts();
    // extern int ss_twr_initiator_sts_no_data(void); ss_twr_initiator_sts_no_data();
    // extern int ss_twr_responder_sts_no_data(void); ss_twr_responder_sts_no_data();
    // extern int tx_rx_aes_verification(void); tx_rx_aes_verification();
    // extern int ss_aes_twr_initiator(void); ss_aes_twr_initiator();
    // extern int ss_aes_twr_responder(void); ss_aes_twr_responder();
    // extern int ds_twr_initiator(void); ds_twr_initiator();
    // extern int ds_twr_responder(void); ds_twr_responder();
    extern int ds_twr_responder_sts(void); ds_twr_responder_sts();
    // extern int ds_twr_initiator_sts(void); ds_twr_initiator_sts();
    // extern int ds_twr_sts_sdc_initiator(void); ds_twr_sts_sdc_initiator();
    // extern int ds_twr_sts_sdc_responder(void); ds_twr_sts_sdc_responder();
    // extern int continuous_wave_example(void); continuous_wave_example();
    // extern int continuous_frame_example(void); continuous_frame_example();
    // extern int ack_data_rx(void); ack_data_rx();
    // extern int ack_data_tx(void); ack_data_tx();
    // extern int gpio_example(void); gpio_example();
    // extern int simple_tx_sts_sdc(void); simple_tx_sts_sdc();
    // extern int simple_rx_sts_sdc(void); simple_rx_sts_sdc();
    // extern int frame_filtering_tx(void); frame_filtering_tx();
    // extern int frame_filtering_rx(void); frame_filtering_rx();
    // extern int spi_crc(void); spi_crc();
    // extern int simple_rx_pdoa(void); simple_rx_pdoa();
    // extern int otp_write(void); otp_write();
    // extern int le_pend_tx(void); le_pend_tx();
    // extern int le_pend_rx(void); le_pend_rx();
    // extern int pll_cal(void); pll_cal();
    // extern int bw_cal(void); bw_cal();
    // extern int double_buffer_rx(void); double_buffer_rx();
    // extern int timer_example(void); timer_example();
    // extern int tx_power_adjustment_example(void); tx_power_adjustment_example();
    // extern int simple_aes(void); simple_aes();


    while (1) {}
}

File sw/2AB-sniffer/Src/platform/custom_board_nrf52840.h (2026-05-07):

/*! ----------------------------------------------------------------------------
 * @file    custom_board_nrf52840.h
 * @brief   Pin definitions for DW3000 / DWM3001C connected to an nRF52840 board.
 *
 *
 * Copyright 2024 (c) Port contributor.  Apache 2.0 License.
 * ----------------------------------------------------------------------------
 */

#include "nrf_gpio.h"
#include "nrf_spim.h"
#include "nrfx_uarte.h"

#ifndef CUSTOM_BOARD_NRF52840_H
#define CUSTOM_BOARD_NRF52840_H

#ifdef __cplusplus
extern "C" {
#endif

// LEDs definitions for PCA10056
//#define LEDS_NUMBER    4
#define LEDS_NUMBER    2

#define LED_1          NRF_GPIO_PIN_MAP(0,3)
#define LED_2          NRF_GPIO_PIN_MAP(1,13)
//#define LED_3          NRF_GPIO_PIN_MAP(,)
//#define LED_4          NRF_GPIO_PIN_MAP(,)
#define LED_START      LED_1
#define LED_STOP       LED_2
//#define LED_STOP       LED_4

#define LEDS_ACTIVE_STATE 0

//#define LEDS_LIST { LED_1, LED_2, LED_3, LED_4 }
#define LEDS_LIST { LED_1, LED_2 }

#define LEDS_INV_MASK  LEDS_MASK

#define BSP_LED_0      NRF_GPIO_PIN_MAP(0,3)
#define BSP_LED_1      NRF_GPIO_PIN_MAP(1,13)
//#define BSP_LED_2      15
//#define BSP_LED_3      16

//#define BUTTONS_NUMBER 4
#define BUTTONS_NUMBER 0
//#define BUTTON_1       11
//#define BUTTON_2       12
//#define BUTTON_3       24
//#define BUTTON_4       25
//#define BUTTON_PULL    NRF_GPIO_PIN_PULLUP

#define BUTTONS_ACTIVE_STATE 0

//#define BUTTONS_LIST { BUTTON_1, BUTTON_2, BUTTON_3, BUTTON_4 }

//#define BSP_BUTTON_0   BUTTON_1
//#define BSP_BUTTON_1   BUTTON_2
//#define BSP_BUTTON_2   BUTTON_3
//#define BSP_BUTTON_3   BUTTON_4




/* ---- DW3000 SPI interface ---- */
#define DW3000_CLK_Pin      NRF_GPIO_PIN_MAP(0,16)   /**< P0.16 - QM33120W SPI clock */
#define DW3000_MOSI_Pin     NRF_GPIO_PIN_MAP(0,17)   /**< P0.17 - QM33120W SPI MOSI  */
#define DW3000_MISO_Pin     NRF_GPIO_PIN_MAP(0,23)  /**< P0.23 - QM33120W SPI MISO  */
#define DW3000_CS_Pin       NRF_GPIO_PIN_MAP(0,20)  /**< P0.20 - QM33120W SPI chip-select (active-low) */

/* ---- DW3000 control / IRQ lines ---- */
#define DW3000_IRQ_Pin      NRF_GPIO_PIN_MAP(0,25)  /**< P0.25 - QM33120W interrupt (rising edge) */
#define DW3000_RST_Pin      NRF_GPIO_PIN_MAP(0,15)  /**< P0.15 - QM33120W hard reset (active-low) */
#define DW3000_WUP_Pin      NRF_GPIO_PIN_MAP(1,2)  /**< P1.02 - QM33120W wake-up pin             */

/* ---- Optional UART debug ---- */
#define RX_PIN_NUMBER    NRF_GPIO_PIN_MAP(0,8)
#define TX_PIN_NUMBER    NRF_GPIO_PIN_MAP(0,7)
#define CTS_PIN_NUMBER   NRF_UARTE_PSEL_DISCONNECTED
#define RTS_PIN_NUMBER   NRF_UARTE_PSEL_DISCONNECTED
#define HWFC             false

#ifdef __cplusplus
}
#endif

#endif /* CUSTOM_BOARD_NRF52840_H */

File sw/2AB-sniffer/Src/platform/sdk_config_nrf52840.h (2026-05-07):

/*! ----------------------------------------------------------------------------
 * @file    sdk_config_nrf52840.h
 * @brief   nRF5 SDK configuration overrides for nRF52840.
 *
 * This file is included INSTEAD OF (or in addition to) the SDK's default
 * sdk_config.h. Place it in your include path before the SDK version so
 * that its defines take priority.
 *
 * Only settings that differ from the nRF52833 defaults used in the original
 * DWM3001C project are listed here. All other settings are inherited from
 * the SDK's sdk_config.h.
 * ----------------------------------------------------------------------------
 */

#ifndef SDK_CONFIG_NRF52840_H
#define SDK_CONFIG_NRF52840_H

/* Sanity check: ensure we are building for nRF52840 */
#ifndef NRF52840_XXAA
  #error "This sdk_config override is for NRF52840_XXAA only."
#endif

/* ------------------------------------------------------------------
 * Board selection
 * With BOARD_CUSTOM the application is responsible for defining
 * all pin numbers (see custom_board_nrf52840.h).
 * ------------------------------------------------------------------ */
#define BOARD_CUSTOM 1

/* ------------------------------------------------------------------
 * SPIM3 is available on both nRF52833 and nRF52840 and supports
 * 32 MHz operation.  No changes needed for the SPI driver.
 * ------------------------------------------------------------------ */
#define NRFX_SPIM_ENABLED       1
#define NRFX_SPIM3_ENABLED      1
#define SPI_ENABLED             1
#define SPI3_ENABLED            1
#define SPI_DEFAULT_CONFIG_IRQ_PRIORITY  6

/* ------------------------------------------------------------------
 * GPIOTE
 * ------------------------------------------------------------------ */
#define GPIOTE_ENABLED          1
#define NRFX_GPIOTE_ENABLED     1

/* ------------------------------------------------------------------
 * Clock driver
 * ------------------------------------------------------------------ */
#define CLOCK_ENABLED           1
#define NRFX_CLOCK_ENABLED      1

/* ------------------------------------------------------------------
 * Logging (Segger RTT back-end)
 * ------------------------------------------------------------------ */
#define NRF_LOG_ENABLED         1
#define NRF_LOG_DEFAULT_LEVEL   4   /* DEBUG */
#define NRF_LOG_BACKEND_RTT_ENABLED  1
#define NRF_LOG_DEFERRED        0

/* ------------------------------------------------------------------
 * Memory configuration
 * nRF52840 has 256 KB RAM so we can afford larger buffers.
 * ------------------------------------------------------------------ */
#define NRF_BALLOC_ENABLED      1
#define NRF_MEMOBJ_ENABLED      1

#endif /* SDK_CONFIG_NRF52840_H */

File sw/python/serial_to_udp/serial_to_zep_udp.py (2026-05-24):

#!/usr/bin/env python3
"""
uart_zep_forward.py — UART-framed ZEP packet bridge for Wireshark.

Reads UART frames from a serial port (produced by wrap_uart_frame() on the
embedded side), verifies their CRC16-CCITT checksum, strips the framing, and
forwards the bare ZEP payload as a UDP datagram to localhost:17754 so that
Wireshark can decode it in real time using its built-in ZEP dissector.

Frame format expected on the serial port:
  [0xAB][0xCD] | length (uint16 LE) | ZEP payload (length bytes) | CRC16 (uint16 LE)
"""
import argparse
import socket
import struct
import sys
import time


# Handle missing pyserial so the user gets an actionable message
# rather than a bare ImportError traceback.
try:
    import serial
except ImportError:
    print("Missing dependency: pyserial. Install with: pip install pyserial", file=sys.stderr)
    sys.exit(1)


# Two-byte sync preamble that marks the start of every UART frame.
# Must match UART_SYNC0 / UART_SYNC1 defined on the embedded side.
SYNC = b'\xAB\xCD'


def crc16_ccitt(data: bytes, poly: int = 0x1021, init: int = 0xFFFF) -> int:
    """
    Compute CRC16-CCITT over *data*.

    Uses the standard CCITT parameters: polynomial 0x1021, initial value
    0xFFFF, MSB-first bit processing.  Must produce identical results to the
    crc16_ccitt() C function on the embedded side so that integrity checks
    across the UART link are meaningful.

    Args:
        data: Byte string to checksum.
        poly: Generator polynomial (default 0x1021).
        init: Initial CRC register value (default 0xFFFF).

    Returns:
        16-bit CRC as an integer in the range [0, 0xFFFF].
    """
    crc = init
    for b in data:
        crc ^= b << 8
        for _ in range(8):
            if crc & 0x8000:
                crc = ((crc << 1) ^ poly) & 0xFFFF
            else:
                crc = (crc << 1) & 0xFFFF
    return crc


def read_exact(ser, n: int) -> bytes:
    """
    Read exactly *n* bytes from the serial port, blocking until they arrive.

    pyserial's ser.read(n) may return fewer than *n* bytes if the timeout
    fires before the buffer fills.  This wrapper retries until the requested
    count is satisfied or the port signals a timeout with an empty read.

    Args:
        ser: Open pyserial Serial instance.
        n:   Number of bytes to read.

    Returns:
        Exactly *n* bytes.

    Raises:
        TimeoutError: If the serial port returns an empty read before *n*
                      bytes have been collected, indicating the device stopped
                      transmitting mid-frame.
    """
    buf = bytearray()
    while len(buf) < n:
        chunk = ser.read(n - len(buf))
        if not chunk:
            raise TimeoutError("Serial timeout while reading frame")
        buf.extend(chunk)
    return bytes(buf)


def find_sync(ser) -> bool:
    """
    Scan the incoming byte stream until the two-byte SYNC preamble is found.

    Reads one byte at a time and keeps a rolling two-byte window.  This
    approach handles partial frames, noise bytes, and mid-stream connection
    starts gracefully — the receiver re-synchronises automatically on the
    next valid preamble rather than getting stuck on stale data.

    Args:
        ser: Open pyserial Serial instance.

    Returns:
        True once SYNC is found.
        False if the serial port times out before SYNC is detected (empty read).
    """
    prev = b''
    while True:
        b = ser.read(1)
        if not b:
            return False
        prev = (prev + b)[-2:]  # Keep only the last two bytes seen
        if prev == SYNC:
            return True


def main():
    # --- Argument parsing ---------------------------------------------------
    ap = argparse.ArgumentParser(description="Read UART-framed ZEP packets from serial and forward to UDP/17754 for Wireshark")
    ap.add_argument("--port",     required=True,           help="Serial port, e.g. COM5 or /dev/ttyUSB0")
    ap.add_argument("--baud",     type=int, default=115200, help="Baud rate")
    ap.add_argument("--host",     default="127.0.0.1",     help="UDP destination host")
    ap.add_argument("--udp-port", type=int, default=17754,  help="UDP destination port")
    ap.add_argument("--timeout",  type=float, default=5.0,  help="Serial timeout in seconds")
    ap.add_argument("--max-len",  type=int, default=6300,   help="Maximum accepted ZEP packet length")
    ap.add_argument("--verbose",  action="store_true",      help="Print packet diagnostics")
    ap.add_argument("--log-wait", action="store_true",      help="Log when no sync has been received yet")
    args = ap.parse_args()

    # --- UDP socket (connectionless, fire-and-forget to Wireshark) ----------
    udp = socket.socket(socket.AF_INET, socket.SOCK_DGRAM)

    # --- Main receive / forward loop ----------------------------------------
    with serial.Serial(args.port, args.baud, timeout=args.timeout) as ser:
        if args.verbose:
            print(f"Listening on {args.port} @ {args.baud}, forwarding to udp://{args.host}:{args.udp_port}")
        synced_once = False     # Used to print "Sync acquired" exactly once
        while True:
            try:
                # Hunt for the two-byte frame preamble.
                got_sync = find_sync(ser)
                if not got_sync:
                    if args.verbose and args.log_wait:
                        print("Waiting for sync...")
                    continue

                if args.verbose and not synced_once:
                    print("Sync acquired")
                synced_once = True

                # Read the 2-byte little-endian ZEP frame length.
                hdr = read_exact(ser, 2)
                zep_len = struct.unpack('<H', hdr)[0]

                # Reject zero-length and suspiciously large frames before
                # attempting to read their payload; avoids stalling or OOM.
                if zep_len == 0 or zep_len > args.max_len:
                    if args.verbose:
                        print(f"Skipping invalid length {zep_len}")
                    continue

                # Read the ZEP frame.
                zep_pkt = read_exact(ser, zep_len)

                # Read the 2-byte little-endian CRC and verify it.
                crc_rx   = struct.unpack('<H', read_exact(ser, 2))[0]
                crc_calc = crc16_ccitt(zep_pkt)
                if crc_rx != crc_calc:
                    if args.verbose:
                        print(f"CRC mismatch rx=0x{crc_rx:04X} calc=0x{crc_calc:04X}")
                    continue    # Discard corrupted frame; re-sync on next preamble

                # Forward the verified ZEP frame over UDP.
                # Wireshark (with a "ZEP" capture filter or dissector on port
                # 17754) will decode this as an IEEE 802.15.4 frame.
                udp.sendto(zep_pkt, (args.host, args.udp_port))
                if args.verbose:
                    print(f"Forwarded {len(zep_pkt)} bytes @ {time.strftime('%H:%M:%S')}")
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

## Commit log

2025-09-17 Updated to exclude some KiCad files
2025-09-17 Added RF module to schematic
    [UWBkit_eval.kicad_sch, rf_module.kicad_sch]
2025-09-19 Added usb port
    [UWBkit_eval.kicad_sch]
2025-09-19 Added connectors
    [UWBkit_eval.kicad_sch]
2025-09-21 Assigned pins to connectors, added battery protection, edited LED footprint
    [UWBkit_eval.kicad_sch]
2025-09-24 First version of the board
    [UWBkit_eval.kicad_pcb, UWBkit_eval.kicad_sch]
2025-09-29 Revised layout to be more compact
    [UWBkit_eval.kicad_pcb]
2025-09-30 Prepared PCB for RPI layout
    [UWBkit_eval.kicad_pcb]
2025-10-02 Added a new variant of the PCB
    [UWBkit_minimal.kicad_pcb, UWBkit_minimal.kicad_sch, rf_module.kicad_sch]
2025-10-02 Progress on minimal design
    [UWBkit_minimal.kicad_pcb]
2025-10-02 Added power led, test points, modified layout
    [UWBkit_minimal.kicad_pcb, UWBkit_minimal.kicad_sch]
2025-10-03 Minor additions
    [UWBkit_minimal.kicad_pcb, UWBkit_minimal.kicad_sch]
2025-10-08 Minor changes, added a footprint with QR code
    [UWBkit_minimal.kicad_pcb, UWBkit_minimal.kicad_sch]
2025-10-15 Generated BOM
    [UWBkit_minimal.kicad_pcb, UWBkit_minimal.kicad_sch]
2025-10-15 Modified links
    [UWBkit_minimal.xlsx]
2025-11-12 Updated pinout for SWD connector
    [UWBkit_minimal.kicad_pcb, UWBkit_minimal.kicad_sch]
2025-11-25 Added mechanical models
    [Assem1.SLDASM, UWBkit_minimal.kicad_pcb, UWBkit_minimal.step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]
2025-12-13 Fixed PCB .STEP export
2025-12-15 PDF export
    [UWBkit_minimal.kicad_sch]
2025-12-18 Remade the lid to accept an OLED display
    [case.SLDPRT, lid_oled.SLDPRT, oled.SLDPRT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]
2025-12-18 Updated parts and assembly
    [lid_oled.SLDPRT, oled_holder.STL]
2026-01-01 Removed unused KiCad project
    [UWBkit_eval.kicad_pcb, UWBkit_eval.kicad_sch, rf_module.kicad_sch]
2026-01-01 Updated BOM link for SWD header
    [UWBkit_minimal.xlsx, UWBkit_minimal_BOM.xlsx]
2026-01-04 Added missing firmware files
    [custom_board.h]
2026-02-01 Added footprint for chip antenna
    [UWBkit_sniffer.kicad_pcb, UWBkit_sniffer.kicad_sch, cpu.kicad_sch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]
2026-02-05 Fixed a missing connection to JTAG
    [UWBkit_minimal.kicad_pcb, UWBkit_minimal.kicad_sch]
2026-02-05 Wired connections to SoC
    [UWBkit_sniffer.kicad_pcb, UWBkit_sniffer.kicad_sch, cpu.kicad_sch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]
2026-02-07 Added components to schematic
    [UWBkit_sniffer.kicad_pcb, UWBkit_sniffer.kicad_sch, cpu.kicad_sch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]
2026-02-08 First version of PCB
    [UWBkit_sniffer.kicad_pcb, UWBkit_sniffer.kicad_sch, cpu.kicad_sch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]
2026-02-10 Modified layout, uncovered RF traces
    [UWBkit_sniffer.kicad_pcb]
2026-02-15 Added reset pullup for CP2014
    [usb_uart_bridge.kicad_sch]
2026-02-15 United 5V rails, modified layout of connectors
    [UWBkit_sniffer.kicad_pcb, UWBkit_sniffer.kicad_sch, cpu.kicad_sch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]
2026-02-15 Added placeholder silkscreen elements
    [UWBkit_sniffer.kicad_pcb]
2026-02-15 Generated preliminary fab files
    [UWBkit_sniffer.kicad_pcb]
2026-02-18 Added connector description
    [UWBkit_sniffer.kicad_pcb]
2026-02-21 Removed UWA.01, added CTS/RTS connections
    [UWBkit_sniffer.kicad_pcb, UWBkit_sniffer.kicad_sch, cpu.kicad_sch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]
2026-02-22 Redone RF trace, repositioned UWC.20 and mounting holes
    [UWBkit_sniffer.kicad_pcb, UWBkit_sniffer.kicad_sch, cpu.kicad_sch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]
2026-02-22 Improved placement of ICs and ports and the board is now smaller
    [UWBkit_sniffer.kicad_pcb, power.kicad_sch, usb_uart_bridge.kicad_sch]
2026-02-22 Moved silkscreen text to be more visible
    [UWBkit_sniffer.kicad_pcb]
2026-02-23 Moved pi-filter past R8 shorting resistor
    [UWBkit_sniffer.kicad_pcb, cpu.kicad_sch, rf.kicad_sch]
2026-02-23 Moved pi-filter
    [UWBkit_sniffer.kicad_pcb]
2026-02-24 Release V1.0
    [UWBkit_sniffer.kicad_pcb, UWBkit_sniffer.kicad_sch, cpu.kicad_sch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]
2026-02-28 Generated BOM for V1
    [UWBkit_sniffer.kicad_sch, UWBkit_sniffer_V1_BOM.xlsx, cpu.kicad_sch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]
2026-03-10 Fixed bottom silkscreen positioning for release V1.1
    [UWBkit_sniffer.kicad_pcb]
2026-03-26 Restructured files
    [Assem1.SLDASM, Assem_oled.SLDASM, UWBkit_minimal.SLDASM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]
2026-05-04 Added STL files for 3D print
    [case_bottom.STL, case_lid.STL]

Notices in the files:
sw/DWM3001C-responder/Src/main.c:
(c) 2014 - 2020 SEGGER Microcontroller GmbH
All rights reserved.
